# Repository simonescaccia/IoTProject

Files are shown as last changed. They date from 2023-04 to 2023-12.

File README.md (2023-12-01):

# Irrigation Water Leakage System

## Description

Our project is designed to offer some smart functionalities to an irrigation system. Our main goal is to keep track of water usage and leakages, in order to avoid the waste of water. In detail, the system provides measurements about water flow at the source and it detects possible water leakages through irrigation pipes, triggering a proper alarm.

[Concept](https://github.com/simonescaccia/Irrigation-Water-Leakage-System/blob/main/Concept.md) provides details from the user perspective, while [Design](https://github.com/simonescaccia/Irrigation-Water-Leakage-System/blob/main/Design.md) provides technical details about the project. Finally, [Evaluation](https://github.com/simonescaccia/Irrigation-Water-Leakage-System/blob/main/Evaluation.md) focuses on performance issues.

Look at our [Hackaster.io tutorial](https://www.hackster.io/508104/water-leakage-detection-system-fc7f69).

## Video

Video of the Prototype in the environment: [prototype](https://www.youtube.com/watch?v=hoUJ2N8BXHc)

Video of the Simulation on IoT-Lab: [simulation](https://youtu.be/vylREJ1_cT4)

Video of the Presentation of the Project: [presentation](https://www.youtube.com/watch?v=7PrMZpjj8rQ)

## People

| People | Linkedin | Github |
|--- |--- |--- |
| Riccardo Gobbato | [Linkedin](https://www.linkedin.com/in/riccardo-gobbato-380674251/) | [Github](https://github.com/RicGobs) |
| Simone Scaccia | [Linkedin](https://www.linkedin.com/in/simone-scaccia-40b631210/) | [Github](https://github.com/simonescaccia) |
| Pasquale Mocerino | [Linkedin](https://www.linkedin.com/in/pasquale-mocerino-29088b1a2/) | [Github](https://github.com/pasqualemocerino) |

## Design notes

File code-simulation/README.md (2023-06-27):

# Irrigation Water Leakage System RIOT code

## IoT-Lab experiment connection
Create a new IoT-Lab experiment with the needed number of nodes for the simulation. In our case, we defined an infrastructure with 8 nodes, one for each ESP32. Then, after properly setting an SSH key on IoT-Lab, connect through the following command:

    ssh <username>@saclay.iot-lab.info
    
Default 4.9 version of ARM gcc toolchain is not compatible, so run:
    
    source /opt/riot.source 
    
In order to check current gcc version the following command is available:
    
    arm-none-eabi-gcc --version
 
In our case, we refer to 2023.04 RIOT-OS version.

Clone RIOT-OS repository with:

    git clone https://github.com/RIOT-OS/RIOT.git -b 2023.04

Then clone our repository:

    git clone https://github.com/simonescaccia/Irrigation-Water-Leakage-System.git

At this point compile the code with:

    <login>@saclay:~/Irrigation-Water-Leakage-System/code$ make clean all

To flash the firmware:

    <login>@saclay:~/Irrigation-Water-Leakage-System/code$ iotlab-node --flash bin/b-l072z-lrwan1/irrigation-water-leakage-detection.elf -l saclay,st-lrwan1,<node-id> -i <experiment-id>
      
The values node-id and experiment-id can be easily retrieved from IoT-Lab dashboard.
    
Now it is possible to access to the RIOT shell running on the node using netcat:
    
    nc st-lrwan1-<node-id> 20000
    
If the console is empty, using:
    
    setup
    
the output will print out.

## Node configuration

Input: node architecture file, self id

Output: how I am (source_lora_ttn node, source_lora_p2p node, fork node, branch node)

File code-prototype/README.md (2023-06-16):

# Irrigation Water Leakage System RIOT code-prototype

## Introduction
In this folder there are three directories, one per each algorithm implemented. <br/>
We suggest to use the algorithm SyncAck because it is the best one, read the evaluation in the documentation for the motivations. <br/>
There is also the code for the MQTT Bridge, this has to be executed in the device that you want to use as bridge for AWS. <br/>

## How to run the code
Firstly, you have to download mosquitto, go to the site https://github.com/eclipse/mosquitto and follow the instructions. <br/>

Secondly, you have to connect your computer and AWS following this guide https://aws.amazon.com/it/blogs/iot/how-to-bridge-mosquitto-mqtt-broker-to-aws-iot/. <br/>

Then, download RIOT from github:

    git clone https://github.com/RIOT-OS/RIOT.git

Go in RIOT folder and then in the directory /example, download here our code, go in the directory of the SyncAck code (you can do the same for the other algorithms):

    cd RIOT/examples/
    git clone https://github.com/simonescaccia/Irrigation-Water-Leakage-System.git
    cd /Irrigation-Water-Leakage-System/code-prototype/code-ack
    
Now try to do make of the code with command (change type of board and port if needed):

    sudo BOARD=esp32-heltec-lora32-v2 BUILD_IN_DOCKER=1 DOCKER="sudo docker" PORT=/dev/ttyUSB0 make all

If all works, connect your board and do (repeat the same thing for the other board, changing the value of the variable "BOARD" to 0 for Source or 1 for Son):

    sudo BOARD=esp32-heltec-lora32-v2 BUILD_IN_DOCKER=1 DOCKER="sudo docker" PORT=/dev/ttyUSB0 make flash term

Now your ESP32 are working and are sending messages to the MQTT topic selected. Open another terminal, go in the correct directory and launch the command:

    cd /Irrigation-Water-Leakage-System/code-prototype/
    python3 client.py
    
This script take the values sent by the ESP32s and redirect them to AWS.

### Common errors
For this project you need two different boards, one for the Source and one for the Son. <br/>
Before launching the code, change the private values of the code like information of the WI-FI and AWS properties.

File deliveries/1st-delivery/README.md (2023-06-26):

# Smart Irrigation System

## People

| People | Linkedin | Github |
|--- |--- |--- |
| Riccardo Gobbato | [Linkedin](https://www.linkedin.com/in/riccardo-gobbato-380674251/) | [Github](https://github.com/RicGobs) |
| Simone Scaccia | [Linkedin](https://www.linkedin.com/in/simone-scaccia-40b631210/) | [Github](https://github.com/simonescaccia) |
| Pasquale Mocerino | [Linkedin](https://www.linkedin.com/in/pasquale-mocerino-29088b1a2/) | [Github](https://github.com/pasqualemocerino) |

## Description

Our project is designed in order to offer some smart functionalities to an irrigation system to keep track of water usage and leakages, in order to avoid the waste of water. In particular the system measures the humidity of the soil, provides a proper water flow to specific crop through the selective opening of solenoid valves and detects possible water leakages through irrigation pipes.

## Links

[Concept](./Concept.md)\
[Design](./Design.md)\
[Evaluation](./Evaluation.md)

## Video

It will be uploaded soon

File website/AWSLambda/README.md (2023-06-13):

# AWSLambda
This folder contains Python scripts used for AWS Lambda functions. 

In detail, `TakeFunctionLambda.py` processes messages sent from LoRa TTN node of our IoT-Lab simulation to our TTN application, and from this application to AWS. Then it inserts obtained information in two DynamoDB tables. 

The function `WaterMonitorFunction.py`, instead, returns information from the two tables, that are accessed by the web application through a proper AWS API Gateway. 

Finally, the function `WaterSensorLambda.py` is an slightly different Python script used for our prototype in order to retrieve data from tables.

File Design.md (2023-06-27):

# Design

## Components

Our infrastructure is composed of:

* ESP32 MCU
* LoRa support for peer and cloud communication
* Water flow sensor
* Led & Buzzer
* Cloud system (AWS) to collect and store data

### ESP32

The ESP32 manages the different sensors and actuators in the infrastructure and exchanges messages with the other microcontrollers and with the cloud. The main technical issue is that the device will be attached to every object of interest and, apart from the source site, they should be battery powered. MCUs wakes up only when a test is needed, so we modulated a proper duty cicle in order to provide a longer battery lifetime. MCU at the source, instead, is connected to a power cord and does not have energy constraints, but a duty cycle is implemented as well.

### LoRa

LoRa is a physical radio communication protocol, based on spread spectrum modulation techniques derived from chirp spread spectrum (CSS) technology. The protocol is supported by our chosen ESP32 MCUs, allowing a low power and long range communication between microcontrollers in order to accomplish distributed tasks.

### Water flow sensors

Water flow sensors are installed at the water source or pipes to measure the flow rate of water. The chosen metric for flow measurement is liters per minute. The structure of the sensor consists of a valve (from which water can pass) and a water rotor along with a Hall effect sensor (a voltage difference is induced in the conductor due to the rotation of the rotor), measuring the sense and the intensity of the flow. When water flows through the valve, it causes a change of speed of the rotor, calculated as output as a pulse signal. The sensor is powered with a 5 V supply voltage of DC.

Water flow sensors used for our protoype can be found [here](https://www.amazon.it/dp/B079QYRQT5?psc=1&ref=ppx_yo2ov_dt_b_product_details)

### Led & Buzzer

A LED is used to provide a visual alarm indication through blinking.</br>
A buzzer is used to provide an acoustic alarm indication through intermitting activation.

### Cloud system

Data are stored on AWS for long term storage. Then these data can be displayed by farmers in order to gain insights about water usage, in detail the water flow at the source, and pipeline leakages, with the indication of detected location.

## How to detect a leakage

As a first step, we have to reason about our main requirement, leakage detection. In particular, we need to do a feasibility study about how to detect a leakage in a pipeline first, and then how to detect it in a distributed system. The following images show our reasoning process. <br> </br>

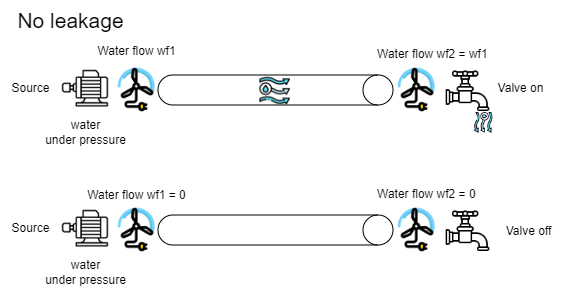
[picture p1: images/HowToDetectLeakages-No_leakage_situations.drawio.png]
no_leakage

<br> </br>
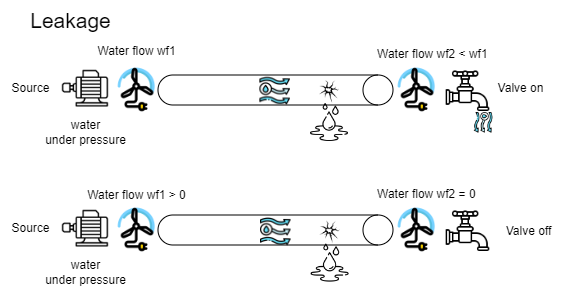
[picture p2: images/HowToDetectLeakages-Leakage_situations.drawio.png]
leakage

<br> </br>
So, by putting the water flow sensors at the extremity of the pipe we can compute the difference of water flow and check if there is a leakage.
If a leakage occur we expect that the water flow at the end of a pipe is different than the water flow at the start.

Our first attempt to detect leakages in distributed infrastructure is the following:
by putting a waterflow sensor befor the fork, we can correctly detect a leakage by computing the difference between the fork water flow and the sum of the branch waterflows. But, it is not enough to satisfy the requirements since we cannot detect which pipe is leaking as in the picture, you can see the same waterflow in both cases but different pipes are leaking.
</br> </br>
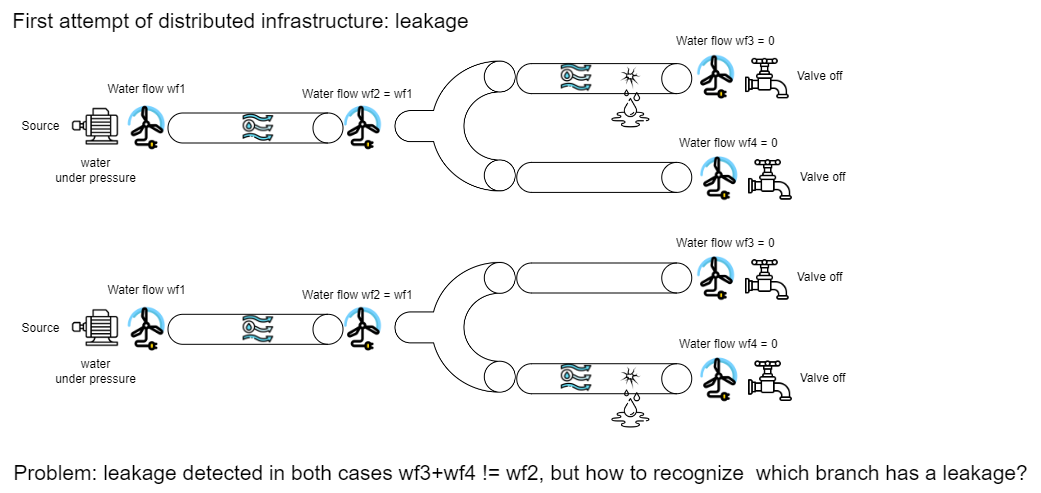
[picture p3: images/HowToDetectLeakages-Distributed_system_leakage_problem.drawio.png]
distributed_problem

<br> <br>
Our proposed solution is to put two water flow sensors insead of one at the fork site. Indeed, in this case, we can detect also the pipe which has a leak.
</br> <br>
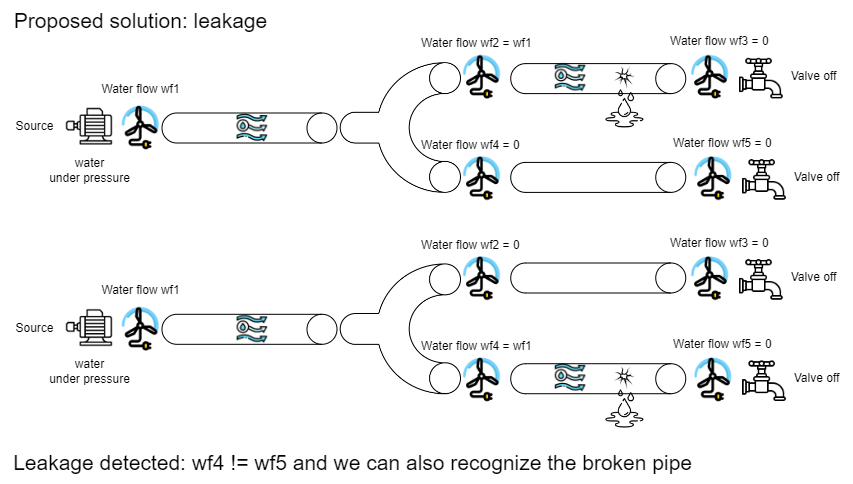
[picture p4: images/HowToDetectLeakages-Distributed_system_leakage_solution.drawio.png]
distributed_solution

<br> </br>
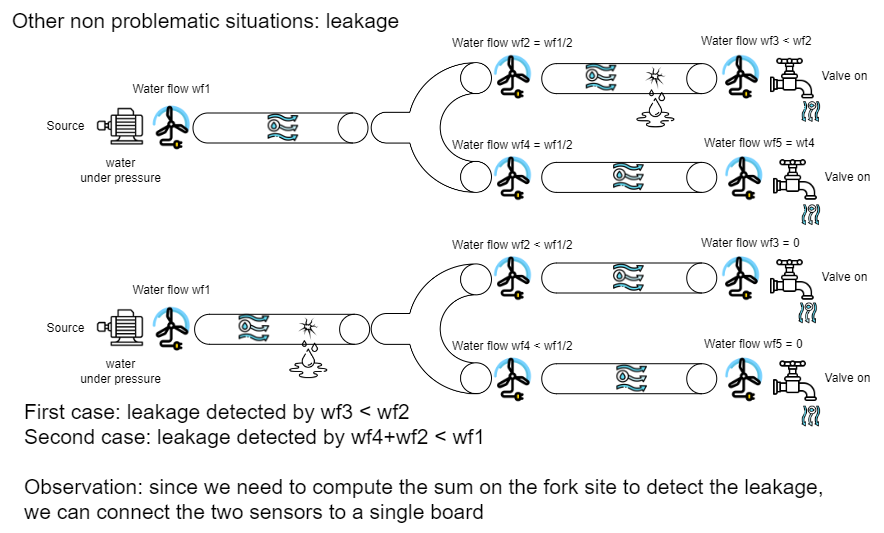
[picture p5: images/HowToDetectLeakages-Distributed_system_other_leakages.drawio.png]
distributed_other


## Architecture

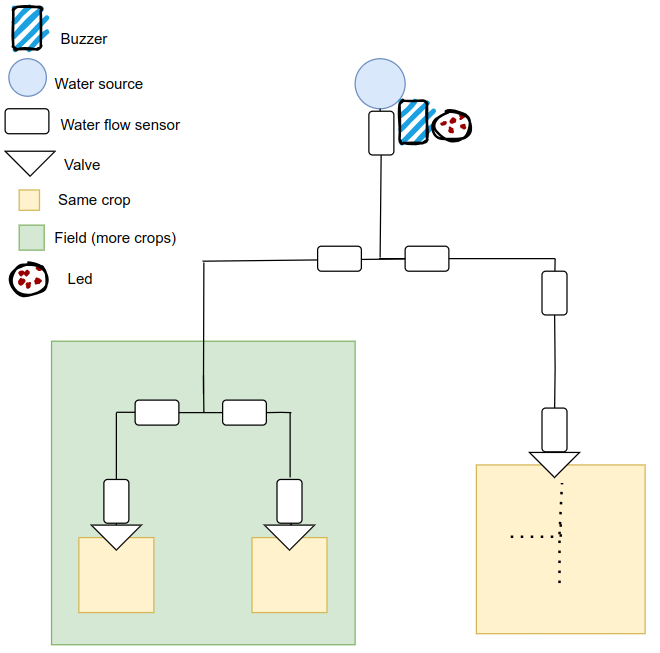
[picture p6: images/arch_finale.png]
field


We propose a tree architecture with a MCU at source site connected to a water flow sensor, a LED and a buzzer. A fork is defined as a site where a single pipe divides itself in two or more output pipes. We place a water flow sensor for each of these diramations, all connected to a single MCU. So. a MCU at each fork site, which can be at different depth levels, is needed. Furthermore, we place a MCU for each pipeline branch, more precisely in correspondence of each irrigation valve, where we place a single water flow sensor connected to the MCU. Our architecture is scalable, so it can be used to control water leakages within a small field with the same crop or to control leakages from pipes irrigating different types of crop in the same field. </br>

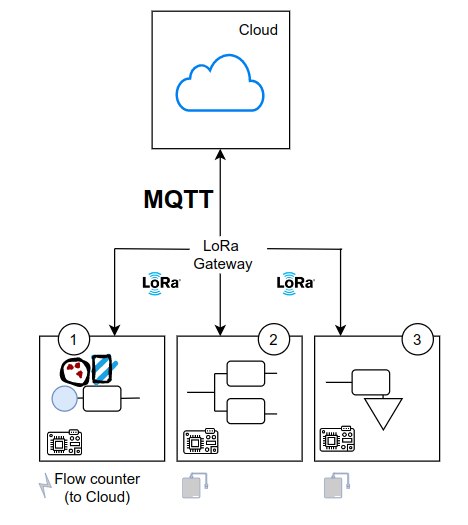
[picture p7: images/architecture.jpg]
architecture


Our system is composed of 3 different pieces:

* MCU near the water source (connected through a power cord) called CHIEF
* MCU near the pipeline fork (using a battery) called FORK
* MCU connected to a water flow sensor at valve site (using a battery) called BRANCH

Every node has an identificative number (in the case of the simulation given by IoT-Lab) and we designed a properly configuration function to extract the information for each node from the topology, given as father-child pairs.
Since in the simulation we used a node for each MCU, our tree architecture can be represented in a more understandable way as follows. </br>

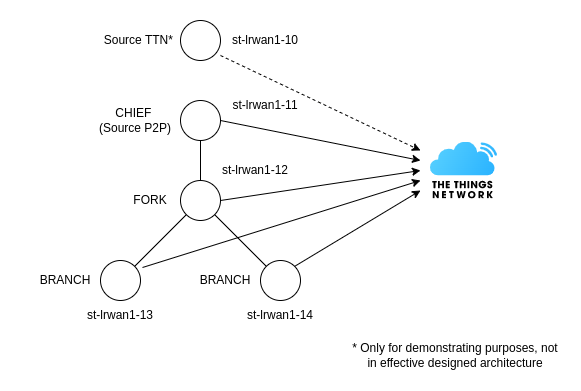
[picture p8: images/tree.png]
tree


In our architecture we preferred to focus our attention on things, with computation performed at nodes rather than in the cloud. So, the cloud only receives (from TTN) data about water flow and leakages that are simply displayed in the GUI. For some techical reasons explained in detail in the description of our simulation, we used a simple node communicating with TTN for demonstrating purposes. However, in the designed architecture each node receiving a flow from the father computes the difference between this flow and its own one and sends data to TTN only in case of leakage.

## Network architecture

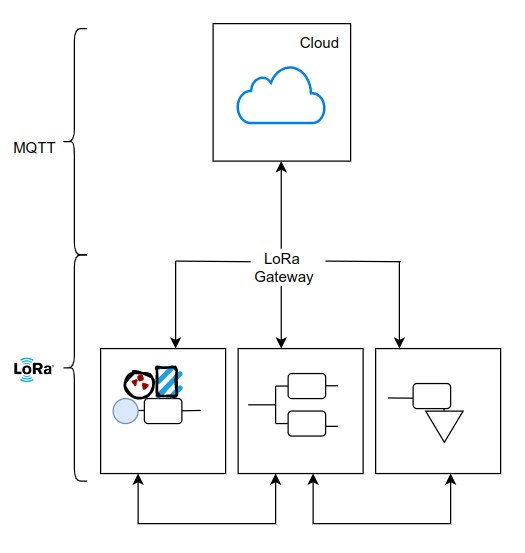
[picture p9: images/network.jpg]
network


The network architecture is focused on checking the actual state of the irrigation system, with a communication between devices based on LoRaWAN and MQTT.

## Prototype

We constructed a real prototype to demonstrate the working principle of the system. It is made up of a linear pipe and two MCUs located at its endopoints, with a water flow sensor for each one, together with a water source and an intermediate valve used to simulate a leakage.

Unfortunately, we found some problems working with LoRa with our chosen ESP32, even if it should be officially supported by RIOT. So, in order to overcome this issue, we decided to switch to WiFi technology only for demonstating purposes. The idea is that when LoRa issue will be hopefully solved soon our project can be adapted with minor changes.
For our prototype, we used the fllowing objects:

* A 1,5 meters long garden hose (20-25 mm ⌀)
* A 1/2 inch garden tap
* A 1/2 inch T-adapter
* 6 metal adjustable hose clamps
* 2 water flow sensors (15-20 mm)
* 2 ESP32 LoRa MCUs  

We started from a 1,5 meters long garden hose with an inner diameter of 20 mm and an outer one of 25 mm. We cut the garden hose into 4 main segments approximately 35 cm long. We placed two segments at the inner endpoints of each water flow sensor and we joined them using the T-adapter. So we connected the tap to the last free endpoint of the T-adapter and the last two segments to the outer endpoints of water flow sensor. We defined a direction for the flow placing the water flow sensors in the correct flow measurement direction. Finally, we connected the water flow sensors to the MCUs and the MCUs to a battery.

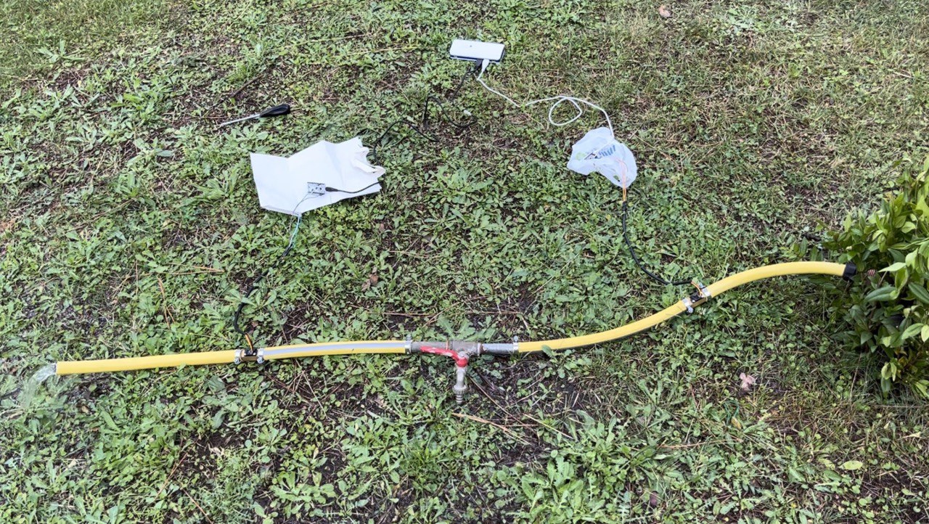
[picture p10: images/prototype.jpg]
prototype


The tap is used to simulate a leakage and it is initially closed. We did not use clamps at first, but we experienced water leaks in correspondence of joints. Therefore we placed 2 clamps at the outer endpoints of each water flow sensor and other 2 for the endpoints of the T-adapter not connected to the tap. In this way we solved the problem of leakages at joints. The water flow sensor of father MCU and the water flow sensor of child MCU are 90cm apart.

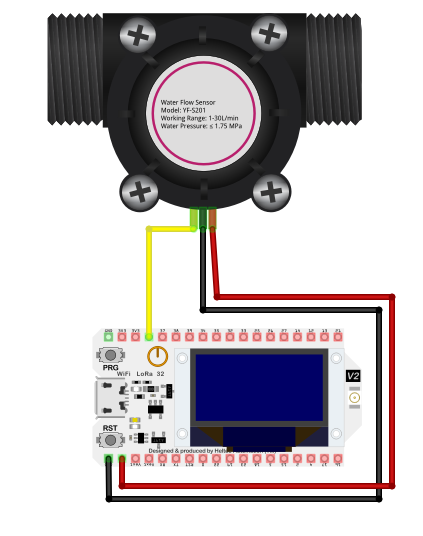
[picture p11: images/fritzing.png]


## Algorithms

### Water leakage detection algorithm

In the following we describe the communication scheme between IoT elements, Edge components, and Cloud components, related to the algorithm for the leakage detection.

We analyse the water flow independently for each segment, intended as the pipe between two adjacent water flow sensors. Given a segment, we will call the node near the water source as 'parent' and the other one as 'child'.
Output water flows at fork site will be evaluated according to given paramters as pipe length or slope.

Test algorithm:

1. Node MCU sends water flow value to its children, if any.
2. If it is a FORK, child MCU computes expected values of water flow, by summing the values of its sensors.
3. Child MCU compares received value with its own value.
4. In case of leakage, child sends an alert to the cloud.

We have tried 3 different algorithms for allow a correct and synchronized test between two diffent nodes. The three algorthms are:

* Ack
* Handdshake
* SyncAck
All the algorithms are available in the directory "code-prototype"

#### Ack

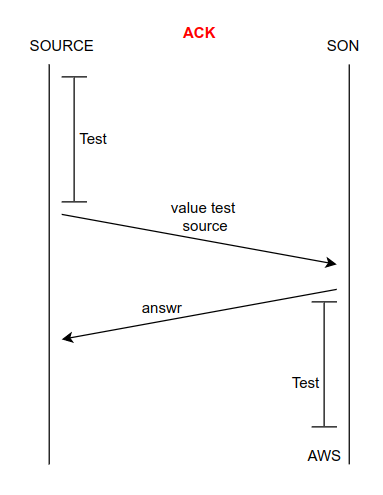
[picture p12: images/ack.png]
ack


This is the first algorithm that we have implemented and it does not work well. Firstly there is a bug in the code, in fact with this code the Son has an higher flow that the Source, and this is not physically possible (if you find the problem, please tell us where is it), Secondly with the data obtained, we have seen that the water flow arriving to the Source (before our architecture) is not stable and the code was not robust against this problem.

In particular the Source controls if there is a water flow, if yes it does the test and sends the value to the Son; the Son obtains the value, sends an "answr" to the Source (used to control the Son is not broken) and starts the test; after that it does the difference between the two values and see if there is a leakage or not, if yes it sends the value of the leakage in L/min to AWS.

For the motivation written before, this system is proned to the false positive and we have stopped the analysis on it.

#### Handshake

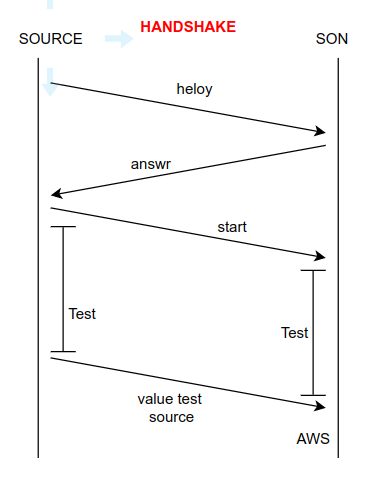
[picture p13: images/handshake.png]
handshake


This is the second algorithm that we have implemented and it works well.

In particular the Source controls if there is a water flow, if yes it sends an "heloy" to the Son, the Son sends an "answr" to the Source, Source sends the message "start" and starts the test; when the Son obtains the "start" it also starts the test; the Source sends to the Son the result of the test and, when the Son has both the values, sees if there is a leakage, if yes it sends the value of the leakage in L/min to AWS.

This system works well but it is uselessly complex and it is less efficient than the next one.

#### SyncAck

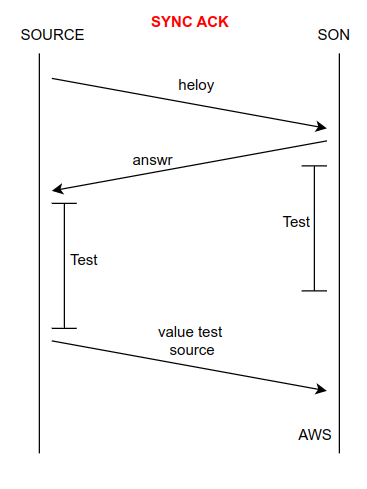
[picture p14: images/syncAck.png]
syncAck


This is the third algorithm that we have implemented and it is the one that will be used in the real scenario.

In particular the Source controls if there is a water flow, if yes it sends an "heloy" to the Son, the Son sends an "answr" to the Source and it also starts the test, Source receives the message "answr" and starts the test; Source sends to the Son the result of the test; when the Son has both the values, sees if there is a leakage, if yes it sends the value of the leakage in L/min to AWS.

This system works well and uses one less message.

In the evaluetion part, it is available the different analysis on the data.

## Simulation

We built a simulation infrastructure on IoT-LAB, to provide a large-scale irrigation water leakage system and to test distributed interaction between MCUs. The communication between nodes is implemented using LoRaMAC, while LoRaWAN and TheThingsNetwork are used to send data to the cloud. Also, we will use this simulation to makes some experiments on energy consumpion using the IoT-LAB monitoring tool.

### Assumptions

The simulation aims to detect leakages in a scalable distributed infrastructure, while the prototype focus on detecting leakages for a single pipe. For this reason, in the simulation we have made some assumptions:

* A code function simulates samples to avoid delays in message propagation, false positives, and all the problems discussed in the prototype. Instead, we will use a logic time to simulate the sampling at the same time.
* Forks on a pipe will divide the water flow into equal parts.
* Since we are simulating samples, we can set the threshold for leakages to 0.

### Iot-Lab Architecture

As mentioned before, to build a scalable infrastucture we need to use three different types of nodes: CHIEF, FORK, and BRANCH. They can cover all the possible cases of a distributed infrastructure.
The minimal architecture of the system should be the following:

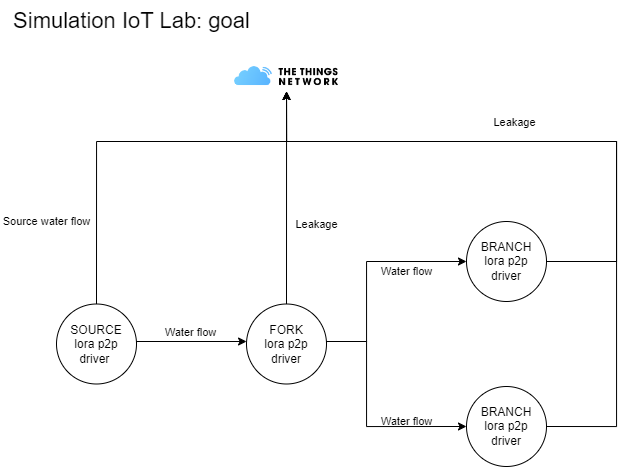
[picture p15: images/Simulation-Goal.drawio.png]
simulation_goal


Node configuration

* Due to the fact that the firmware is distributed, we need to use the same firmware for all the nodes. For this reason, we need to build a configuration file named config.c that can be used for all the nodes, to understand which type of node is and who are its children.
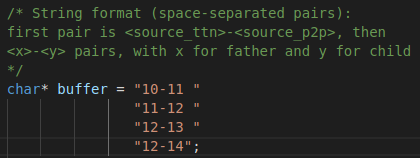
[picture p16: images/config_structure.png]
config_structure

* After flashing the firmware we need to assign an ID to each node compliant with the configuration file.
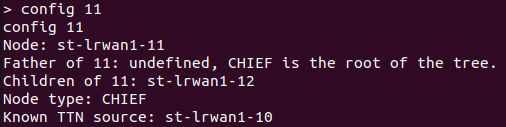
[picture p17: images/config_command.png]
config_command


Parameters

* Since requirements want to detect leakages in a day, we have decided to simulate a day in 60 seconds. Also, we have introduced a parameter called NUMBER_OF_SENDING_PER_DAY that represents the number of samples sent by the node in a day, in order to implement the duty cycle. For the simplicity of the demo, we have set this parameter to 3 but the value for the real application it is discussed in the Evaluation page.

Sample generator

* The sample generator is a function that simulates the sampling of the water flow. Its aim is also to test the various leakage scenario discussed in the 'How to detect a leakge' paragraph.

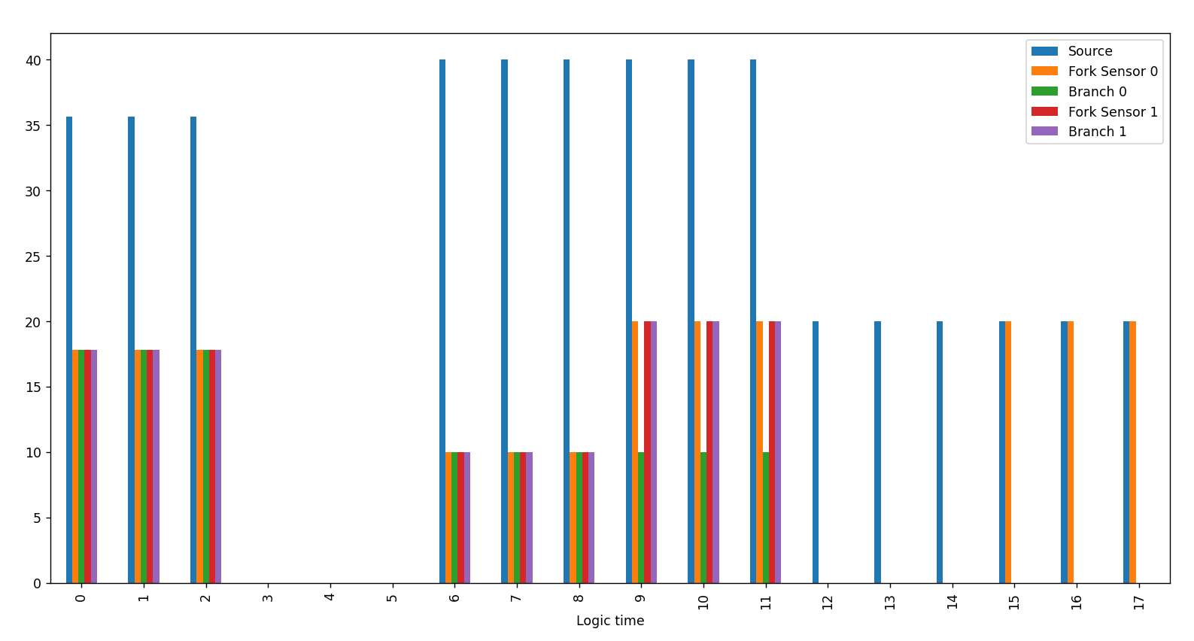
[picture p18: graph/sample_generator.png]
sample_generator


* logic_time in [0, 2]: Simulate no LEAKAGE with water usage - Test also float water flow mesurements
* logic_time in [3, 5]: Simulate no LEAKAGE without water usage
* logic_time in [6, 8]: Simulate a LEAKAGE between the CHIEF and the FORK with water usage
* logic_time in [9, 11]: Simulate a LEAKAGE between the FORK and a BRANCH with water usage
* logic_time in [12, 14]: Simulate a LEAKAGE between the CHIEF and the FORK without water usage
* logic_time in [15, 17]: Simulate a LEAKAGE between the FORK and a BRANCH without water usage

Comunication protocols

* The nodes communicate with each other using RIOT-OS Semtech SX127x radios drivers implementation, sending asynchronous messages containing the water flow value.
* Each node sends leakage messages to The Things Network (TTN) using a RIOT adaption of Semtech LoRaMAC implementation.

But, during the implementation we have found some difficulties on integrating the Semtech LoRaMAC implementation with the RIOT-OS Semtech SX127x radios drivers implementation. In particular, initialising both the drivers on the same node, causes some conflicts that invalidate the communication of both node-TTN ans node-to-node.
For this reason we have decided to use another node to connect our infrastructure to TTN, and in order to be able to send leakage messages generated by the nodes using LoRaMAC, we have decided to pick these leakage information directly from the sample generator since building a UART communication between the nodes requires time that can be used to solve our initial problem i.e. the conflicts between the LoRa drivers.

So, our implementation is the following:

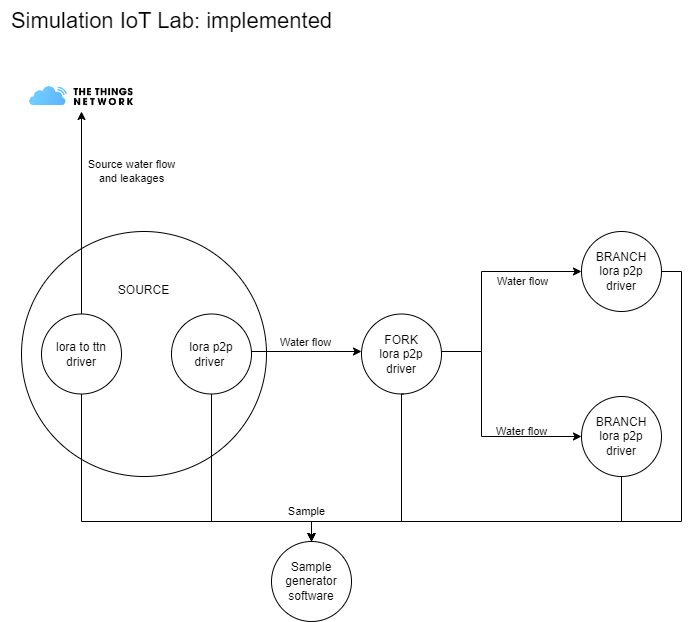
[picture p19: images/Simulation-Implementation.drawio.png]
simulation_implementation


Messages

* Semtech SX127x radios drivers implementation allows to send messages of at most 32 bytes in broadcast mode. This implies that a node in the listen mode can receive messages from all the nodes in the range. For this reason, we have decided to use a message structure that contains the following information:

  * The app id: 0000
  * The id of sender node
  * The id of receiver node
  * A flag that indicates if the message is a value
  * The value of the water flow
  * The logic time

* When a node receives a message, it checks if the message is sent by our infrustructure and if the message is directed to it.
* We have observed that RIOT SX127x drivers fails to handle messages with a payload higher than 32 bytes which causes a stack overflow and the crash of the node. That's a critical problem because messages sent by external nodes can cause the crash of our infrastructure.

Radio

* The radio can't be used to send a message and listen at the same time. Then, with a certain probability that increases with the number of sending messages per day, during the message transmission, incoming messages can be lost.

### Open Issues

* Integration of lora sx127x drivers for p2p communication and loramac for ttn communication.
* Using real samples instead of simulated ones.
* Crash of the node when receiving messages with a payload higher than 32 bytes.

## Dashboard

### AWS Architecture

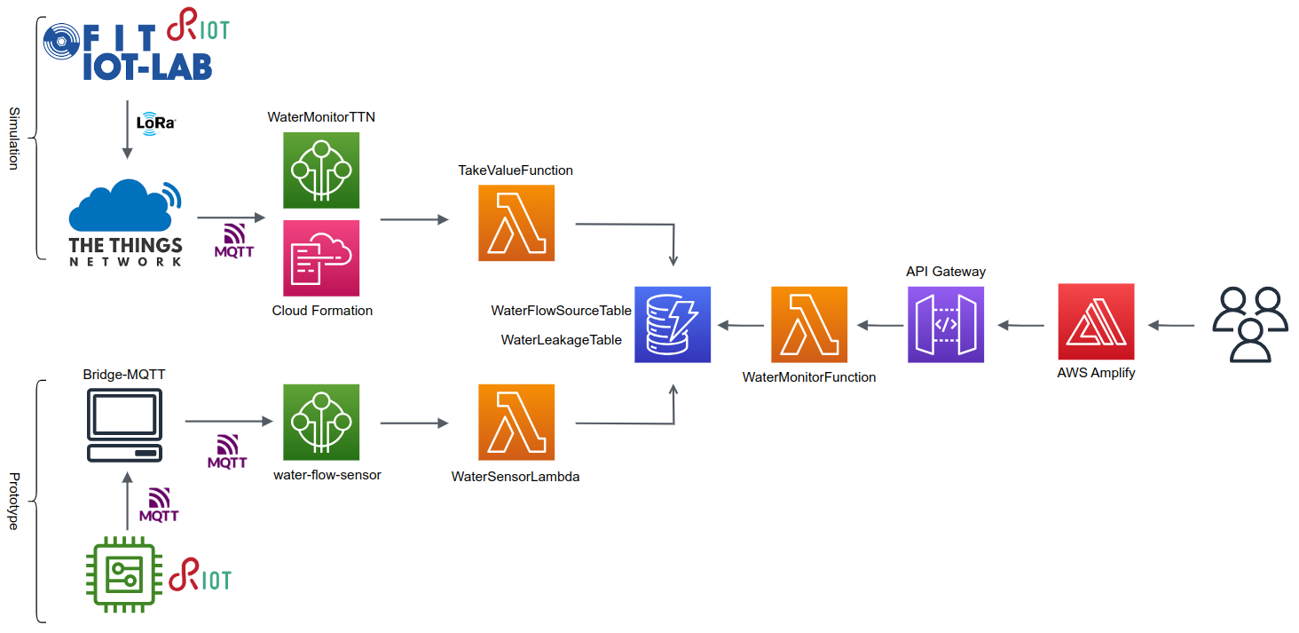
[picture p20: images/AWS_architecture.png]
AWS

The AWS architecture above shows our cloud design. In detail, data are generated both from the prototype and the simulation, but sent to AWS through a MQTT-Bridge for the prototype and TTN for the simulation. Data are sent to AWS IoT Core, using also AWS CloudFormation in the case of TTN. With two proper AWS Lambda functions data are stored in two NoSQL DBs, one for the water flow at the source and one for water leakages. With a separate unique Lambda function, data are retrieved form DBs and associated to an API deployed with AWS API Gateway. The website frontend, taken data dynamically from API endpoint, has been deployed with AWS Amplify.

### Website

Here it is a demonstration of website content:

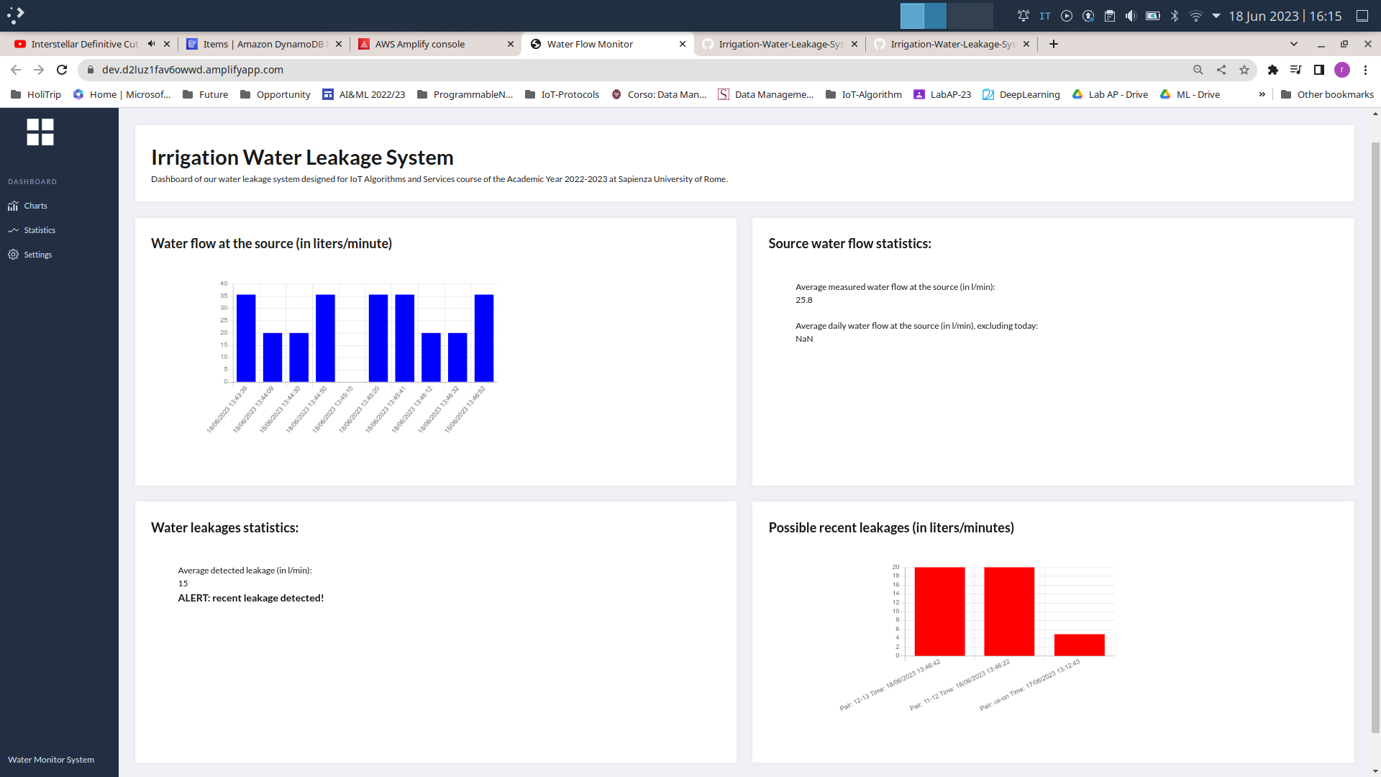
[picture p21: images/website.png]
website


From the website user can monitor water flow at the source looking at last 10 measurements displayed in the upper graph and checking some statistics about average water flow. A proper alert is shown in case of leakage, with leakages displayed in the lower graph with correct location and quantity. Also here, some statistics can be retrieved.

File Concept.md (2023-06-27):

# Concept

## Problem

Today irrigation does often not keep into account possible water leaks from watering pipes. This superficial management is leading to a huge waste of water, which is one of main causes of drought. Agriculture is the most water demanding sector, with the 40% of total water usage per year in Europe.
In Italy over 26 billion of cube meters of water per year are consumed: around 55% is reserved for agriculture, 27% for the industry and 18% for the city. However, withdrawal of water effectively exceeds 33 billion of cube meters per year: this difference is motivated by the waste of around 22% of total water and 17% of these leakages are related to the agricultural sector. However, our project can also be used to monitor the state of regular water distribution system, if a proper adaptation is given.

## Proposed solution

Our proposed solution consists of an interface through which it is possible to monitor the irrigation system. The user can know if a leakage is detected and where it is located, as well as the flow of water at the source site. Another available information is the past water usage schedule, with the relative periodical measurements of water flows.

## Use cases

Our system allows to do the following tasks:

* Leakages detection, quantification and localization
* Water usage monitoring

## User requirements

The starting point of our analysis is the collection of user requirements. In our context, there are some fixed parameters, mainly related to the chosen infrastructure, while other parameters should be finetuned according to the specific final user of the application, ideally a farmer owning a variable field. To cope with this issue, we made reasonable assumptions about these parameters, and we also guaranteed the scalability of the system according to user needs.

### Alarm system

We thought about suitable actuators to use in order to indicate an alarm condition. A simple LED with a buzzer are certainly a good option.
Obiouvsly, it makes no sense to place these actuators in the middle of a field, because it is unlikely that someone will see or hear something. Instead, they can be placed near water source, so they can be easily noticed and constantly connected to electric power.

### Events

The main events we are interested in are certainly water flow changes. We wish to monitor the water flow at the source and also to know about current possible leakages as the results of a proper water leakage detection algorithm comparing flow changes at different nodes of the irrigation system.

### Communication protocol

LoRa is a suitable technology for different reasons:

* It uses low bandwidth, and this is a great advantage in our context. In fact, we need to exchange simple data, namely water flow measurements, so LoRa is certainly a good option.
* It can send data on long ranges. It is not an immediate advantage in our architecture, because we implemented a peer-to-peer communication with adjacent nodes. However, it can be very useful firstly to reach also far LoRa gateways and on large scale systems to exchange data between distant nodes, if needed.
* It works with low power consumption, and this is a crucial added value to the protocol since we use battery-powered MCUs.

### Energy consumption

* We thought about the best battery lifetime for our MCUs and our conclusion was to reason over the needed sampling cycles and the utilization period of the system. So, 1 year of battery life was considered as a good option.
* We also thought about the possibility to recover energy from water flow sensor dynamics, for example with a dynamo. However, this solution was not feasible for our hardware because of the impossibility to access to the enclosed rotor in a proper way.

## HOW WE HAVE WORKED
We have created three subtopic, you can see all this work in [Design](https://github.com/simonescaccia/Irrigation-Water-Leakage-System/blob/main/Design.md) and [Evaluation](https://github.com/simonescaccia/Irrigation-Water-Leakage-System/blob/main/Evaluation.md):
1. Prototype:
* build the physical prototype, solving the technical problems
* create different algorithms to synchronize the nodes
* connect prototype and AWS with MQTT
* take data to choose the best algorithm
* take data to set a correct threshold
2. Simulation in IoT-Lab:
* build the infrastructure of the simulation, solving the technical problems
* send data between nodes with lora-semtech
* create a sample generator function to simulate water flow rates and leakages
* take data of the energy consumption
3. Connection of IoT-Lab and AWS:
* create a node that send data to TTN using the sample generator function
* integrate TTN and AWS
* create the rules, the dynamoDB and the lambda functions to work with the data
* create the website page with Amplify

## Possible improvements
There are some possible improvements for the future of this project:
* Fixing the problem of the libraries lora-semtech and lora-wan to remove the redundant Source TTN
* Transpose the code of the simulation in a real environment using some boards with a working lora-wan library
* Adding the buzzer and the led
* Using real samples instead of simulated ones, in IoT-Lab
* Crash of the node when receiving messages with a payload higher than 32 bytes, in IoT-Lab

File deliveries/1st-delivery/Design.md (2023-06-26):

# Design

## Architecture 
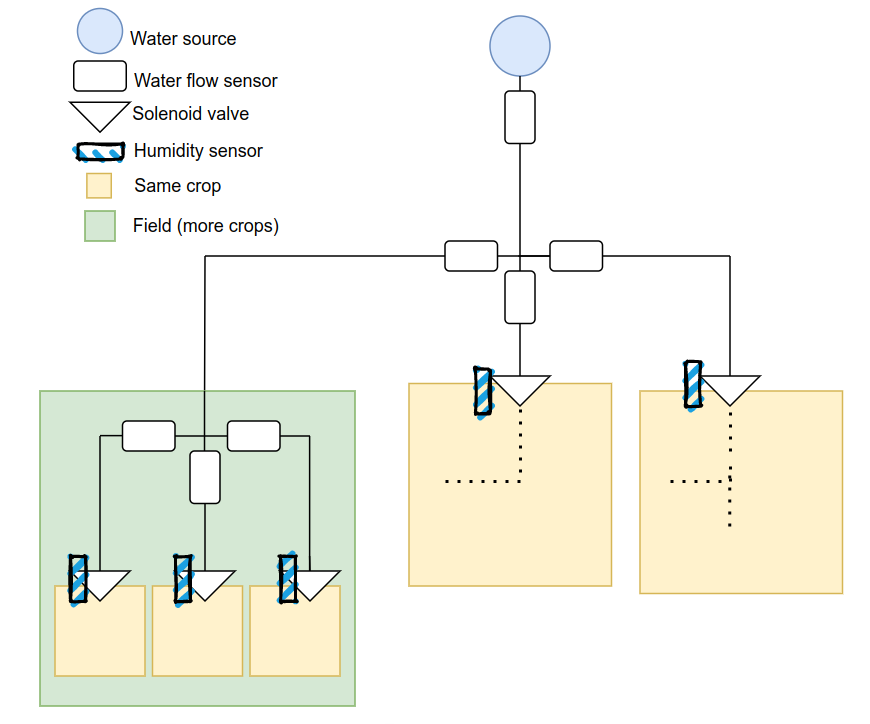
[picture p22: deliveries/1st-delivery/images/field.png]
Field1
 <br/>
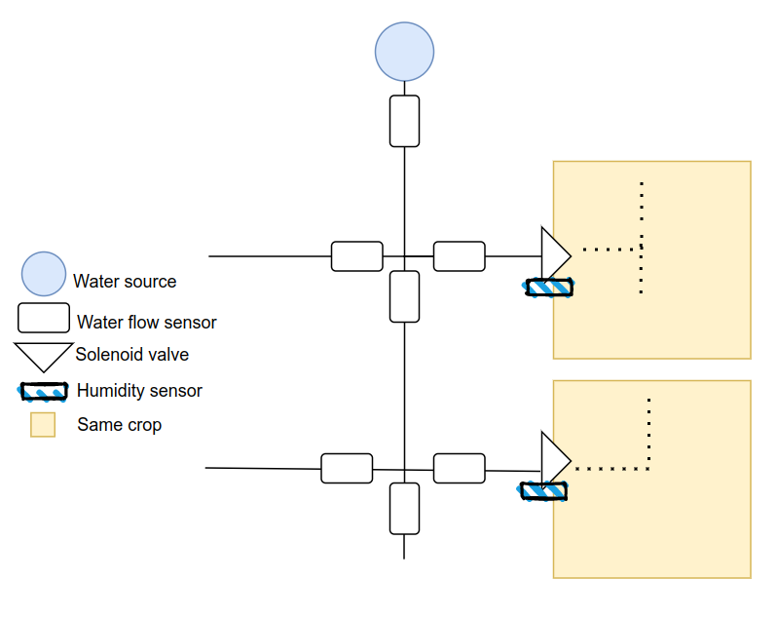
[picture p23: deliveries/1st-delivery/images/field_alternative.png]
Field2
 <br/>
Our architecture is scalable and can be used to control the water within a small field, if there is the same crop, or can be used to control different types of crop in the same field. For every field a MCU at the fork site (that can be at different depth levels) is needed, plus a MCU for each pipeline branch.</br>
We have proposed two different possibilities of set of fields (we will analyse which one is the better or if there are other possible architecture).

## High level diagram
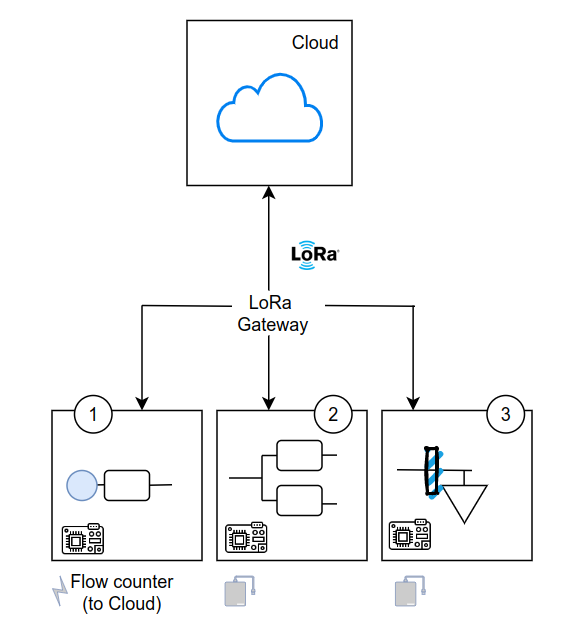
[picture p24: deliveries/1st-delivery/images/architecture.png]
architecture
 <br/>
Our system is composed of 3 different pieces:
* MCU near the water source (connected through a power cord) called CHIEF
* MCU near the pipeline fork (using a battery) called FORK, with an ID for the fork and a NUMBER for each branch water flow sensor
* MCU connected to a soil humidity sensor and a solenoid valve (using a battery) called BRANCH and with a NUMBER (consistent with the NUMBER value in the relative FORK)

## Components
Our infrastructure is composed of:
* ESP32 MCU with LoRa support for peer and cloud communication 
* Water flow sensor
* Soil humidity sensor 
* Solenoid valve
* Cloud system (AWS) to collect and store data

### ESP32
The ESP32 manages the different sensors and actuators in the infrastructure and exchanges messages with the other microcontrollers and with the cloud. The main technical issue is that the device will be attached to every object of interest and thus should be battery powered:
* CHIEF is connected to a power cord and does not have energy problems
* FORK wakes up rarely and only when a test is needed, so it has a small duty cicle
* BRANCH wakes up periodically in order to check the humidity of the soil and possibly irrigate crop

### LoRa
LoRa is a physical radio communication protocol, based on spread spectrum modulation techniques derived from chirp spread spectrum (CSS) technology. The protocol is supported by our chosen ESP32 MCUs, allowing a low power and long range communication between microcontrollers in order to accomplish distributed tasks.

### Sensors
#### Water flow sensors
Water flow sensors are installed at the water source or pipes to measure the flow rate of water. The relative metric is as liters per hour or cubic meters, to be scaled in our context. The structure of the sensor consists of a plastic valve (from which water can pass) and a water rotor along with a Hall effect (a voltage difference is induced in the conductor due to the rotation of the rotor) sensor, measuring the sense and the intensity of the flow. When water flows through the valve, it causes a change of speed of the rotor, calculated as output as a pulse signal. The sensor contains three wires, one for supply voltage (5 V of DC), one for the ground and one to collect output from Hall effect sensor. 

#### Soil humidity sensors
Soil humidity sensors are fork-shaped probes inserted into the soil, with two exposed conductors, hence acting as a variable resistor. The resistance varies inversely with soil humidity. In fact capacitance is used in order to measure dielectric permittivity of the soil, which is a function of the water content. The sensor produces an output voltage proportional to the dielectric permittivity (so inversely proportional to resistance), and therefore the water content of the soil (soil moisture level). Only four pins are required to connect: AO (Analog Output), generating analog output voltage, DO (Digital Output) indicating whether the soil moisture level is within the limit, VCC for power supply (from 3.3 V to 5 V) and GND for the ground.

### Actuators
#### Solenoid valves
Solenoid valves are electromechanically operated valves converting electric energy into mechanical energy. The main purpose is to automatically regulate the movement of water, removing the need of manual control. The actuator consists of a solenoid (or electromagnet) and a valve. The electromagnetic coil within the solenoid (activated with energy supply) is employed to either open or close the valve orifice through a plunger.

### Cloud system
Data are stored on AWS for long term storage. These data can then be queried by farmers in order to gain insights about water usage and pipeline leakages. The farmer can also select a particular crop for a field.

## Network architecture 
network <br/>
The network architecture is focused on checking the actual state of the irrigation system, with a communication between devices based on LoRaWAN and MQTT. We will also make some considerations about the scalability of different possible network schemes.

## Algorithms 
### Water leakage detection algorithm
messages <br/>
This is the communication scheme between IoT elements, Edge components, and Cloud components, related to the algorithm for the leakage detection.

### Automated irrigation algorithm
We provide a pseudocode sketch of the automated mechanism of irrigation:

    def automated_irrigation(humidity_threshold):

        humidity_level = get_humidity() // From soil humidity sensor
    
        if (humidity_level < humidity_threshold):
            open()  // Open signal to solenoid valve
        
            while (humidity_level < humidity_threshold):
                wait(time_interval) // Wait some time to make humidity change
                humidity_level = get_humidity()
            
            close()  // Close signal to solenoid valve

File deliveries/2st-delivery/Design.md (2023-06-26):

# Design

## Architecture

field <br/>

We propose a tree architecture with a MCU at source site connected to a water flow sensor, a LED and a buzzer. A fork is defined as a site where a single pipe divides itself in two or more output pipes. We place a water flow sensor for each of these diramations, all connected to a single MCU. So. a MCU at each fork site, which can be at different depth levels, is needed. Furthermore, we place a MCU for each pipeline branch, more precisely in correspondence of each irrigation valve, where we place a single water flow sensor connected to the MCU. Our architecture is scalable, so it can be used to control water leakages within a small field with the same crop or to control leakages from pipes irrigating different types of crop in the same field. </br>

Since in the simulation we used a node for each MCU, our tree architecture can be represented in a more understandable way as follows.

tree <br/>

## High level diagram

architecture <br/>
Our system is composed of 3 different pieces:

* MCU near the water source (connected through a power cord) called CHIEF
* MCU near the pipeline fork (using a battery) called FORK, with an ID for the fork and a NUMBER for each branch water flow sensor
* MCU connected to a water flow sensor at valve site (using a battery) called BRANCH and with a NUMBER (consistent with the NUMBER value in the relative FORK)

## Components

Our infrastructure is composed of:

* ESP32 MCU with LoRa support for peer and cloud communication 
* Water flow sensor
* LED
* Buzzer
* Cloud system (AWS) to collect and store data

### ESP32

The ESP32 manages the different sensors and actuators in the infrastructure and exchanges messages with the other microcontrollers and with the cloud. The main technical issue is that the device will be attached to every object of interest and thus should be battery powered:

* CHIEF is connected to a power cord and does not have energy problems
* FORK and BRANCH wakes up only when a test is needed, so we modulated a proper duty cicle in order to provide a longer battery lifetime

### LoRa

LoRa is a physical radio communication protocol, based on spread spectrum modulation techniques derived from chirp spread spectrum (CSS) technology. The protocol is supported by our chosen ESP32 MCUs, allowing a low power and long range communication between microcontrollers in order to accomplish distributed tasks.

### Sensors

#### Water flow sensors

Water flow sensors are installed at the water source or pipes to measure the flow rate of water. The relative metric is as liters per hour or cubic meters, to be scaled in our context. The structure of the sensor consists of a plastic valve (from which water can pass) and a water rotor along with a Hall effect sensor (a voltage difference is induced in the conductor due to the rotation of the rotor), measuring the sense and the intensity of the flow. When water flows through the valve, it causes a change of speed of the rotor, calculated as output as a pulse signal. The sensor is powered with a 5 V supply voltage of DC.

You can find our water flow sensor here: https://www.amazon.it/dp/B079QYRQT5?psc=1&ref=ppx_yo2ov_dt_b_product_details

### Actuators

#### LED
A LED is used to provide a visual alarm indication through blinking. 

#### Buzzer
A buzzer is used to provide an acoustic alarm indication through intermitting activation.

### Cloud system

Data are stored on AWS for long term storage. These data can then be queried by farmers in order to gain insights about water usage and pipeline leakages.

## Prototype architecture
For our prototype, we used the fllowing objects:
* A 1,5 meters long garden hose (20-25 mm ⌀)
* A 1/2 inch garden tap
* A 1/2 inch T-adapter
* 6 metal adjustable hose clamps (16-25 mm)
* 2 water flow sensors 
* 2 ESP32 LoRa MCUs  

We started from a 1,5 meters long garden hose with an inner diameter of 20 mm and an outer one of 25 mm. We cut the garden hose into 4 main segments approximately 35 cm long and a smaller one around 10 cm long. We placed two segments at the endpoints of each water flow sensor and we joined them using the T-adapter. We connected the tap to the last free endpoint of the T-adapter and the smallest pipe segment to the tap dispenser. So we connected the water flow sensors to the MCUs. 
The tap is used to simulate a leakage and it is initially closed. We did not use clamps at first, but we experienced water leaks in correspondence of joints. Therefore we placed 2 clamps at the endpoints of each water flow sensor and other 2 for the endpoints of the T-adapter not connected to the tap. 

The final protoype architecture is the following.

## Network architecture 

network <br/>
The network architecture is focused on checking the actual state of the irrigation system, with a communication between devices based on LoRaWAN and MQTT. We will also make some considerations about the scalability of different possible network schemes.

## Algorithms

### Water leakage detection algorithm

This is the communication scheme between IoT elements, Edge components, and Cloud components, related to the algorithm for the leakage detection.

We analyse the water flow for each segment, intended as the pipe between two adjacent water flow sensors. Output water flows at fork site will be evaluated according to given paramters as pipe length or slope.

Algorithm idea (CHIEF duty cycle):

(DUE_TEST is set to true every 24 hours, NO_TEST is initialized to 0)

1. If flag DUE_TEST is set or NO_TEST is set, CHIEF checks if there is water flow (regular water usage monitoring).
2. If there is a water flow, it starts the test and sets the flags to 0.
3. If there is not a water flow, it sets NO_TEST.

Test algorithm:

1. Node MCU sends water flow value to its children.
2. If it is a FORK, child MCU computes expected values of water flow
3. Child MCU compares received value with its own value.
4. In case of error, child sends an alert to the cloud.

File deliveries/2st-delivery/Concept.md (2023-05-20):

# Concept

## Problem

Today irrigation does often not keep into account possible water leaks from watering pipes. This superficial management is leading to a huge waste of water, which is one of main causes of drought. Agriculture is the most water demanding sector, with the 40% of total water usage per year in Europe.
In Italy over 26 billion of cube meters of water per year are consumed: around 55% is reserved for agriculture, 27% for the industry and 18% for the city. However, withdrawal of water effectively exceeds 33 billion of cube meters per year: this difference is motivated by the waste of around 22% of total water and 17% of these leakages are related to the agricultural sector. However, our project can also be used to monitor the state of regular water distribution system, if a proper adaptation is given. 

## Proposed solution

Our proposed solution consists of an interface through which it is possible to monitor the irrigation system. The user can know if a leakage is detected and where it is located, as well as the flow of water at the source site. Another available information is the past water usage schedule, with the relative periodical measurements of water flows.

## Use cases

Our system allows to do the following tasks:

* Leakages detection, quantification and localization
* Water usage monitoring

## User requirements
The starting point of our analysis is the collection of user requirements. In our context, there are some fixed parameters, mainly related to the chosen infrastructure, while other parameters should be finetuned according to the specific final user of the application, ideally a farmer owning a variable field. To cope with this issue, we made reasonable assumptions about these parameters, and we also guaranteed the scalability of the system according to user needs.

### Detect water leakages
* How can we detect leakages? Conceptually, we measure the water flow at different adjacent sites of the irrigation system and we compare these measurements in order to detect anomalies, according to a specific detection algorithm.
* The accuracy is computed considering the percentage of correct leakage identification on the total number of experiments.
* We also thought about the possibility to binary classify every state as faulty or as correct, focusing on the analysis of False Positive and False Negative events.

### Reaction time
We thougt about a proper time bound on the interval from leakage manifestation until detection. Some common values for water flow rate given by irrigation pumps are from 20 to 80 liters of water per minute. Now, there is much variability as concerns the irrigation procedure, depending on the type of crop. However, in most cases, the irrigation procedure should last only few minutes per day. Assuming also a severe leakage, it is difficult that more than 30% of water will be lost. So, in the worst case, from 6 to 24 liters of water per minute will be lost. A reasonable assumption is to tolerate at most 24 hours of no detection. These considerations are at the basis of our concept of duty cycle.

### Alarm system
We thought about suitable actuators to use in order to indicate an alarm condition. A simple LED with a buzzer are certainly a good option.
Obiouvsly, it makes no sense to place these actuators in the middle of a field, because it is unlikely that someone will see or hear something. Instead, they can be placed near water source, so they can be easily noticed and constantly connected to electric power.

### Events 
The main events that we are interested in are certainly water flow changes. We wish to monitor the water flow at the source and also the one at different sites of the system, in order to compare measurements and detect possible changes of flow.

### Communication protocol
LoRa is a suitable technology for different reasons:
* It uses low bandwidth, and this is a great advantage in our context. In fact, we need to exhange simple data, namely water flow measurements, so LoRa is certainly a good option.
* It can send data on long ranges. It is not an immediate advantage in our architecture, because we implemented a peer-to-peer communication with adjacent nodes. However, it can be very useful firstly to reach also far LoRa gateways and on large scale systems to exchange data between distant nodes, if needed.
* It works with low power consumption, and this is a crucial added value to the protocol since we use battery-powered MCUs.

### Energy consumption
* We thought about the best battery lifetime for our MCUs and our conclusion was to reason over the needed sampling cycles and the utilization period of the system. So, 1 year of battery life was considered as a good option.
* We also thought about the possibility to recover energy from water flow sensor dynamics, for example with a dynamo. However, this solution was not feasible for our hardware because of the impossibility to access to the enclosed rotor in a proper way.

## Simulation
We built a simulation infrastructure on IoT-LAB, in order to provide a large scale irrigation water leakage system and to test distributed interaction between MCUs. In detail, the system scheme is tree-based, with a root node corresponding to the source MCU, intermediate nodes corresponding to fork MCUs and leaf nodes corresponding to MCUs at valve site. The communication between simulated devices is implemented using LoRaMAC, while LoRaWAN and TheThingsNetwork are used to send data to the cloud.

## Prototype
We construct a real prototype to demonstrate the working principle of the system. It is made up of a linear pipe and two MCUs located at its endopoints, with a water flow sensor for each one, together with a water source and an intermediate valve used to simulate a leakage.

Unfortunately, we found some problems working with LoRa with our chosen ESP32, even if it should be officially supported by RIOT. So, in order to overcome this issue, we decided to switch to WiFi technology only for demonstating purposes. The idea is that when LoRa issue will be hopefully solved soon our project can be adapted with minor changes. Even if we will not obiouvsly have the same performance of LoRa, the procedure of evaluation is identical.

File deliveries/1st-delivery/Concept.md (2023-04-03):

# Problem
Today irrigation is still handled in some cases with manual activation of water valves. On the other hand, watering automation is often a simple standard neither keeping into account the effective needs of the soil nor possible water leaks from watering pipes. This superficial management is leading to a huge waste of water, which is one of main causes of drought.

# Proposed solution
Our proposed solution consists of an interface through which it is possible to monitor the irrigation system. The user can know if a leakage is detected and where it is located, as well as the flow of water at the source site and the current humidity of the soil in correspondence of each solenoid valve. Another available information is the past irrigation schedule, with the relative periodical measurements of humidity of the soil (every hour). 

# Use cases 
Our system allows to do the following tasks:
* Leakages detection, quantification and localization
* Automated water flow regulation
* Water usage monitoring and management

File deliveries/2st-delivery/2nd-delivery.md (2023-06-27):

# 2nd delivery

## Comments received

* Explain how a leak is detected and why we have choosen this architecture.
* Explain the problematics about the integration of RIOT LoraWan driver and the LoraMac driver (ttn vs p2p).
* Duty cycle: asynchronicity vs synchronicity to exchange messages.
* Sensing: how to avoid data noise. Possible solution: sliding window. Compare more samplings vs one sampling with a bigger duration.

## Changes

The most important changes in this delivery are:

* The first version of the prototype.
* First considerations about the algorithms for exchange messages between nodes.
* First try to formalize energy consumption, considering the algorithms choosen.
* First experiments on IoT Lab: leakage detection on a distributed system.

## Future work

* Experiments on prototype data and on IoT Lab, focussing on energy.
* Reasoning about improvement of the first version of the prototype and energy consumption.
* Web architecture: AWS.
* Improve the documentation, showing all the reasoning behind the choices made.

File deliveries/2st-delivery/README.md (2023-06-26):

# Irrigation Water Leakage System

## People

| People | Linkedin | Github |
|--- |--- |--- |
| Riccardo Gobbato | [Linkedin](https://www.linkedin.com/in/riccardo-gobbato-380674251/) | [Github](https://github.com/RicGobs) |
| Simone Scaccia | [Linkedin](https://www.linkedin.com/in/simone-scaccia-40b631210/) | [Github](https://github.com/simonescaccia) |
| Pasquale Mocerino | [Linkedin](https://www.linkedin.com/in/pasquale-mocerino-29088b1a2/) | [Github](https://github.com/pasqualemocerino) |

## Description

Our project is designed to offer some smart functionalities to an irrigation system. Our main goal is to keep track of water usage and leakages, in order to avoid the waste of water. In detail, the system provides measurements about water flow in different locations and it detects possible water leakages through irrigation pipes, triggering a proper alarm.

[Concept](./Concept.md) provides details from the user perspective, while [Design](./Design.md) provides technical details about the project. Finally, [Evaluation](./Evaluation.md) focuses on performance issues.

## Links

[Concept](./Concept.md)\
[Design](./Design.md)\
[Evaluation](./Evaluation.md)

## Video

It will be uploaded soon.

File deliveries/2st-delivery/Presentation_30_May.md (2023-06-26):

# Problems

## Algorithms to avoid false positives on leakage detection

ack <br>
handshake <br>
syncAck <br>

## Simulation on IoT-Lab

### Goals

- Detect leakages in a distributed infrastructure.
- Use LoRa protocols to exchange messages.
- Run experiments with various algorithms to measure energy consumption using monitoring tools.

### Done

simulation-done

### Doing

simulation-doing

### To Do

simulation-todo

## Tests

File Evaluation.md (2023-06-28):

# Evaluation

## Evaluation methodology: Overall System

As a general performance evaluation of the system, we wanted to detect if a water leak occurs within 24 hours, in order to detect water leakages without tolerating more than one day of water losses. We wanted also to know wich pipe is leaking.

We used the following metrics to evaluate the performance of the system:

1. Leak is dectected within 24 hours
2. The pipe is correctly identified

## Evaluation methodology: Individual Components

We wish to evaluate the power consumption of MCUs that are not attached to a power cord, so for the FORK and the BRANCH MCUs.

+ Power supply of source site MCU is provided by a power cord, hence there are no specific constraints on power consumption.
+ MCUs at fork sites and crop site, due to the limited workload, we wish to obtain a battery life equal to the total period of irrigation.

## Algorithms Performances

### Water leak detection Algorithm Problems

Before designing a water leak detection algorithm, we focused on the dynamics of water in pipes. Since we are dealing with an irrigation system, a reasonable assumption is to consider **water in pipes under pressure**. It means that there are never empty pipes. Now, we can have two conditions, either stationary water or moving water, due to the increasing pressure at the source during irrigation time. This means that we can ignore the specific condition when doing a test, because the difference between adjacent flows will be bounded in both cases if there is no leakage, and not bounded otherwise. The detection algorithm starts from the source and propagates through the tree topology, always with the same logic for every father-child pair. The father sends water flow information to the child, which makes a proper computation and compares the obtained value with the received one, using a specific threshold. In case of leakage detection, it will communicate the leakage to the cloud through the LoRa gateway.

One of the main problems related to the test is related to synchronization, because of the delay related to transmission latency. We thought about an handshaking approach to take into account this discrepancy and to compare water flows starting the sampling process at two close moments.

1. Test propagation phase
2. Leak notification

The complexity will change depending on the number of FORKs, we have choose the topology of the Design.

The three algorithms proposed in the design phase have been tested. 

The test of the Ack algorithm has shown that there is a problem in the code (intially we thought it is caused by the use of threads in the program, after we understood is linked to the water flow sensor) and that the water flow before our system (that we consider always present) is not stable and this issue has to be solved by the synchronization algorithm.<br/>

The problem of stability of the initial water flow can be seen in the following image in which there is a segmentation of the lines of the graph. In x axis there are the samplings (3 s each )which are done one after the other in a small time (5 min max). <br/>

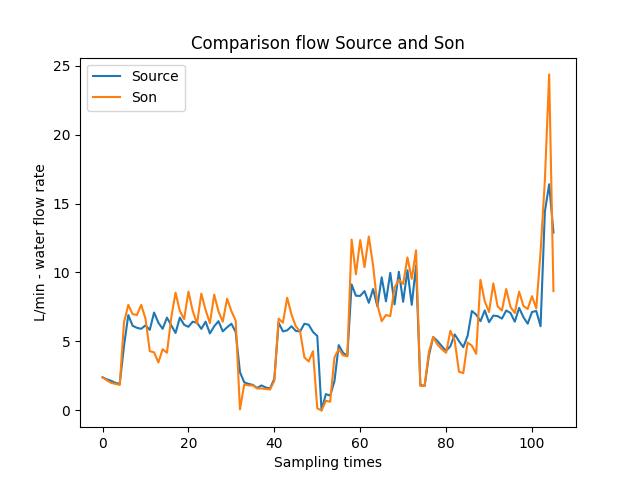
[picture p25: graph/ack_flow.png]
ack
 <br/>
About the Ack algorithm, it is possible to notice that it is good to detect a leakage but it says that the water flow of the Son is always higher than the water flow of the Source, and this can lead to error, so it is not the worst algorithm implemented.<br/>

The following image shows the test of the ack algorithm and it is possible to observ the big difference between Source and Son. Here the samplings are done in a period of a month for each graph. In the next graphs, when there is more blue line, it means there is a leakage.<br/>
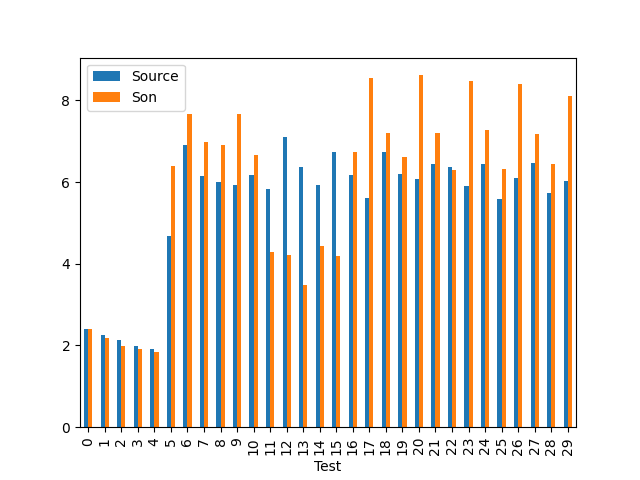
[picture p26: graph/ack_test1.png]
ack1
<br/>

About the Hanshake algorithm, it is perfect to detect the leakage and the trend of the Son higher than the Source is disappeared. There still is an error of the turbines, that we will face in the next chapter.<br/>

The following image shows the test of the Handshake algorithm and it is possible to observ a smaller difference between Source and Son. But there still is a trend in which the Son is higher than the Source.<br/>
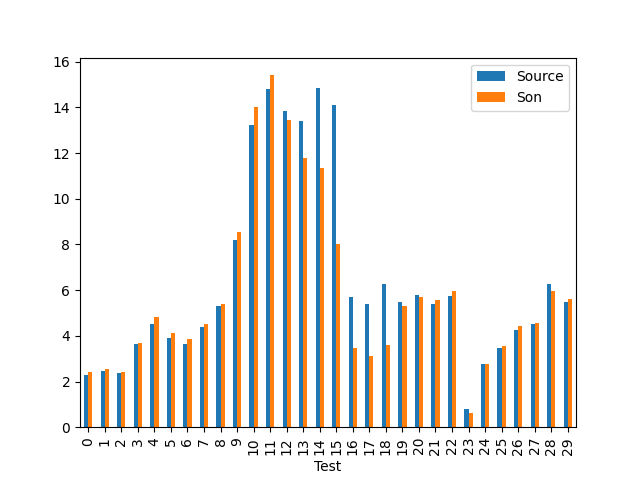
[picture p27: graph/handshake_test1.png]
h1
<br/>

In the end, about the syncAck algorithm, it is possible to see the same trend of the handshake algorithm but with one less message. There is also here the error of the turbines.<br/>

The following image shows the test of the SyncAck algorithm and it is possible to observ a smaller difference between Source and Son. Here the trend is that the Son is higher than the Source.<br/>
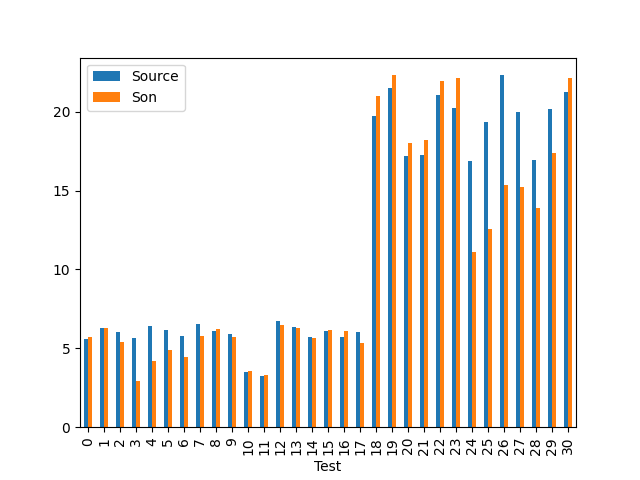
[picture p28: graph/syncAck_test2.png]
s2
<br/>

The following image shows another the test of the SyncAck algorithm, but here the trend is the opposite. This suggests a problem in the water flow sensor.<br/>
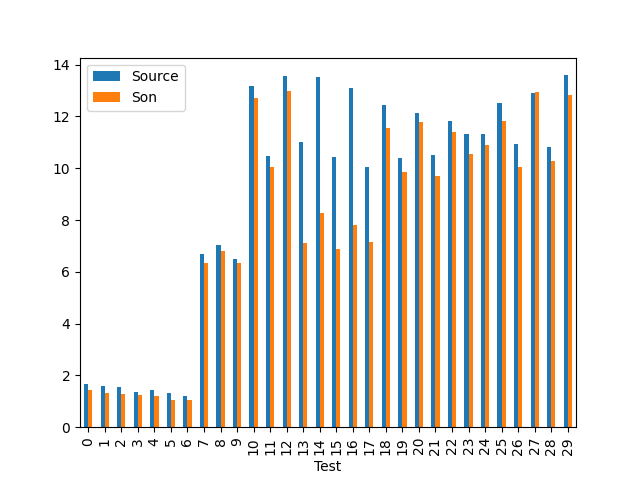
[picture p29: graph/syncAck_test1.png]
s1
<br/>

### Water leak detection Algorithm Solutions

After several tests, and using the considerations done before, we have found that one water flow sensor has some problems and detect less impulses. 

Not having other sensors, we have decided to put the best sensor in the Source and the worst in the Son, so we will have an higher Source in a NO leakage situation.

### Water leak detection Threshold

We have done some analysis to set a correct threshold in our algorithms to limit the presence of false positives and false negatives.<br/>

We have chosen the syncAck as the final algorithm because it uses one message less.
We have analysed the time of the SyncAck algorithm to understand the error that can be created and to use this values for the calucus of the energy consumption.
We have analysed that the standard deviation is high and this means that there is a large distribution of the data, in particular this means that the time taken by the messages and the code is fluctuating. Looking at the scheme, it is possible to understand the time of the messages and also the quality of the synchronization of the algorithms.<br/>
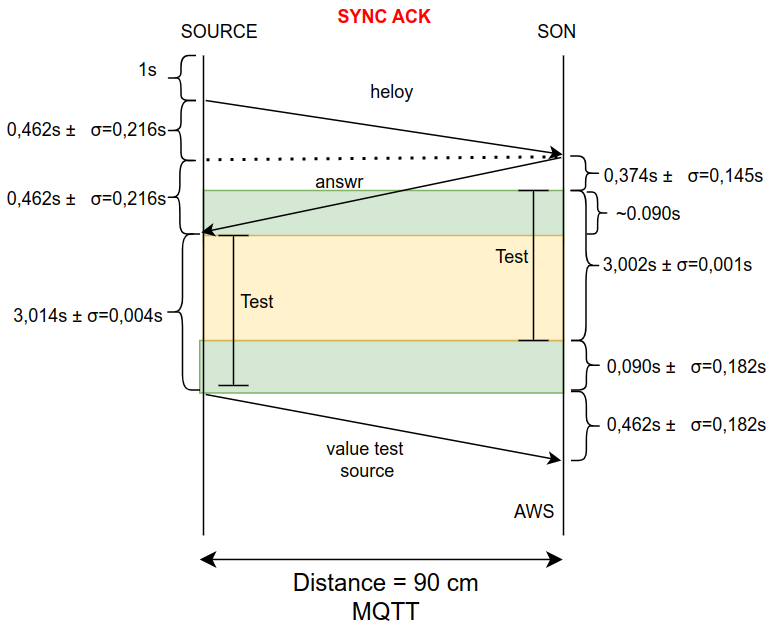
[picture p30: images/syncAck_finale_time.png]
s
<br/>
Here the messages take 0.462 s while the latency of the two samplings is 0.552 s (time in the Son between the end of the test and the arrival of the value of the Source). This means that the Source has ended the test 0.090 s before the Son. So Son and Source have an error of synchronization of 0.090 s. 

<br/>**Difference**<br/>
To find the error of the algorithm we have to decide the time of testing: now is 3s but if we increase it, the influence of the error derived by the synchronization problem is less.The proportion is 0.090s : (TimeSampling) = x : 100. The FlowMax is 30 l/min.

With influence we mean: **$FlowMax \cdot \frac{0.090 \cdot 100}{TimeSampling}$**:

We have analysed three times of testing. 
* TimeSampling of 3s: 3% of influence, 0.90 L/min difference of water flow rate
* TimeSampling of 5s: 1.8% of influence 0.54 L/min difference of water flow rate
* TimeSampling of 10s: 0.9% of influence 0.27 L/min difference of water flow rate

So we take 10s of sampling time to limit the possible error. We do not increase more the sampling time because there will be a trade off with the energy.

Now it is important to discuss this values. The 0.27 L/min is the **possible difference of L/min** between the Source and the Son. This is the worst case scenario but it is important to analyse the algoritmic error in the worst case.<br/> 

It is important to focus also on the instrumental error.

In the last days, we have also thought that this holds also for the time of the handshake algorithm. But we have not checked sperimentally.

In conclusion, because we have done this observation lately, at this point we have choose the **SyncAck algorithm** because it uses one message less. We will see after that the handshake algorithm is not too much more consuming than the SyncAck. <br/>
Then we have choose a **sampling time of 10 seconds** to have a longer analysis of the environment and to reduce the algorithmin error.

We have done another consideration.

The water enter in the first turbine, then it has to flow on the pipeline and arrives in the second turbine. So if the water is too muxh slower than the time of latency, the water of the first turbine taken by the sampling is different from the water of the sampling of the Son. It is important to analyse the speed of the water and the time from the Source to the Son. In particular in our case, the water takes:

* diameter of pipeline: 0.015m
* area of circle: 0.00018 $m^{2}$
* water flow of water max (worst case): 30 L/min = 0.5 L/s
* distance: 0.9 m
  
$$speed of water= \frac{0.5 \cdot 10^{-3}}{0.00018} = 2.83 \frac{m}{s}$$ 
$$time = \frac{2.83}{0.9} = 0.32 s$$

Meanwhile the water is complete different for a distance of:
$$time = \frac{2.83}{distance} = 10 s$$
$$distance = 2.83 \cdot 10s = 28.3 m$$

With this observation, to deal with the algorithmic error, we have to assume a constant water flow rate before the Source.  .

### Turbine error

Another significant error of the architecture is the instrumental error of the water flow sensor. Because of we have not another turbine with the correct value of the water flow or other instruments, we have run the system for several tests and we have analysed the difference between the values of Source and Son. We have observed the difference because the water flow before our application is not costant (decided by the public pipeline). It is important to observ that this error is influenced by the algorithmic error too. We have taken in consideration also the handshake algorithm.

The following image shows the test of the Handshake algorithm with the best water flow sensor in the Son.
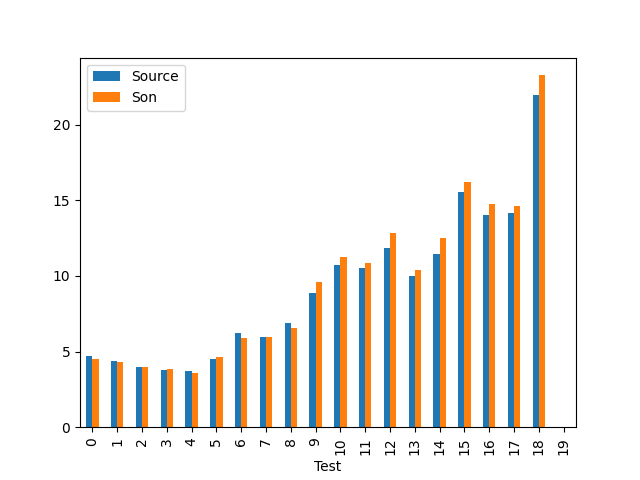
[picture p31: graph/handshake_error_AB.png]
h3AB
<br/>

The following image shows the test of the Handshake algorithm with the best water flow sensor in the Source.
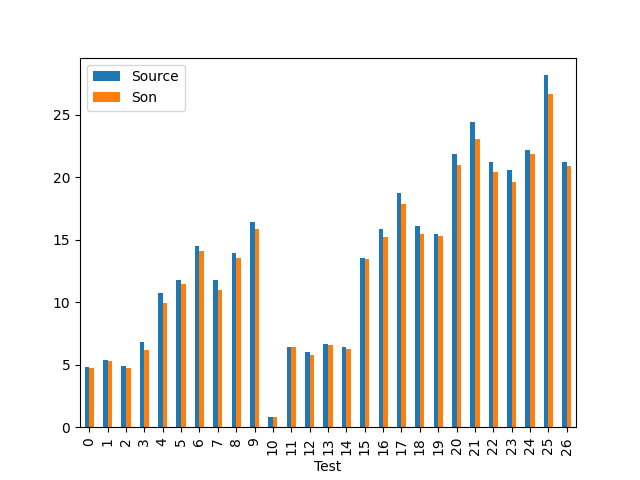
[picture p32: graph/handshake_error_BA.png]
h3BA
<br/>

The following image shows the test of the SyncAck algorithm with the best water flow sensor in the Son.
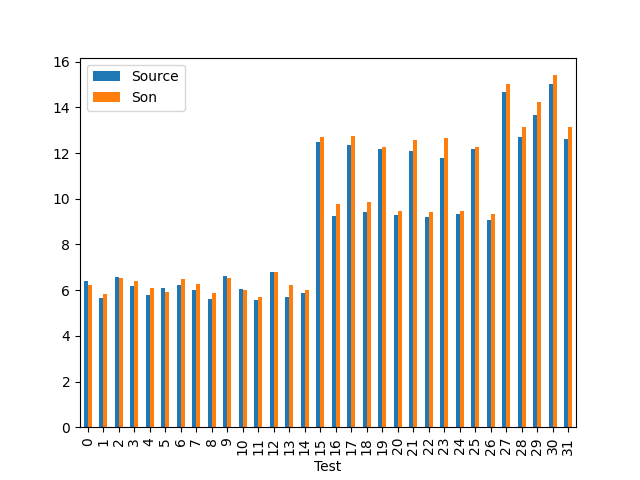
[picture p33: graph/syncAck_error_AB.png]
s3AB
<br/>

The following image shows the test of the SyncAck algorithm with the best water flow sensor in the Source.
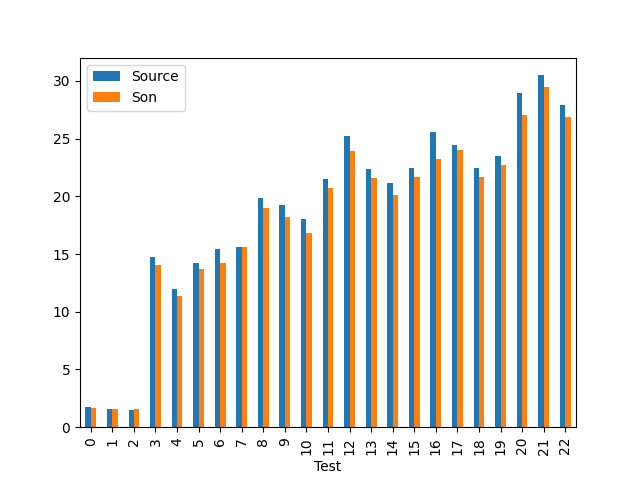
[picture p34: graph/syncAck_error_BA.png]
s3BA
<br/>

The system is proned to have the Son with an higher water flow value, if you put turbine A before turbine B, but this happens because the turbine A is less efficient. <br/>
For our prototype and with a distance of 90cm between the nodes, based on the consideration of the several approssimations, We have initially fought to put a threshold of 1 L/min, but then we have done more considerations.<br/>
We have first set a fixed scenario: 
* turbine B = Source 
* turbine A = Son
Then, we have done a lot of tests changing time of sampling and water flow rate. <br/>
With the analysis of the algorithmic error done before, we thought that an higher sampling was more accurate but the data has not shown this. The tests are done with the use of the syncAck, the table below shows the error rate for the different situation: <br/>

|flow x time| 3s | 5s | 9s |
|--- |--- |--- |--- |
| 0-30 L/min | 0.84 L/min | 0.49 L/min | 0.74 L/min |
| 0-10 L/min | 0.14 L/min | 0.29 L/min | 0.13 L/min |
| 10-20 L/min | 0.58 L/min | 0.67 L/min | 0.76 L/min |
| 20-30 L/min | 1.11 L/min | 1.16 L/min | 1.10 L/min |

The first line is not relevant because there are not enough data and are not distributed well.<br/>
Then, it is possible to note that the difference is not caused by the different time of sampling, but by the different water flow rate: this lead to say that the main error is the error of the turbines and not the error of the algorithm. <br/>
So, we can decide to use the syncAck algorithm knowing that it uses one message less, not keeping in mind the algorithmic error. <br/>





<br/>
We have analysed these data to fix a threshold for the detection of the leakages, and we have done the mean of **(flowSource-flowSon)x100/flowSource** %:

* 3s -> 4,29%
* 5s -> 6,34%
* 9s (done 9s and not 10s because of a problem of MQTT) -> 4,30% <br/>

We have decide to take 10s for the sampling and this will be similar to 9s result, so in this situation we can put a fixed threshold of > 2L/min or dynamic threshold flowSource-flowSon > 5% flowSource L/min. The dynamic threshold is more efficient because it is more accurate in the lower water flow rate. We have done some sperimental test but the system was proned to false positives. So below there are our conclusions.

#### Conclusions on the threshold

Finally, for the threshold, we will give this observation:
1. We did some tests and considering the average, we observed that in a No leakage situation there is a 5% difference between Source and Son, due to the error of a turbine (instrumental error).
2. We then observed that, based on the changes in the flow before the source (therefore on the stability of the flow rate of the pipeline), there may be an average possible error of 0.9%, due to the algorithmic error.
3. We have tried to apply the 5% threshold but experimentally we found too many false positives. We tried 7% and 10%. We have judged that 10% is acceptable.
4. Finally considering that the turbines in a NO leakage situation have an unexpected 5% error; assuming that there is not the same problem for the future system, we will have a threshold of 5%.
5. There is the problem of the speed of the water, in our case it takes 0.32 s to go from Source to Son. This gives a final 4.1% of possible algorithmic error.
6. In general, the threshold will depend on the properties of the particular system (distance of nodes, width of pipe, error of turbine).
7. Why did it happen? 
* First of all we have done many approximations.
* The standard deviation is high and we have understood it as an unreliability of the mean. 
* Finally, the conduct of the test affects the result: the position of the cell phone and the turbines varies the times of the messages (and therefore the algorithmic error).
* The stability of water flow rate before the Source has been probably good during the training of the threshold and bad in the test.

### Energy consumption

#### Duty cycle

Our requirement is not to tolerate a water loss of more than one day, so we wish to detect a leakage within 24 hours. Now, since the leakage is an unpredictable event, we cannot define a precise strategy apriori, but we want to indentify the best one in order to minimize power consumption. We compute this strategy analitically. In the first following analysis, we do not make any assumption about synchronization of nodes. Firstly, for simplicity, we focus on a simple father-child pair, since the same reasoning holds for every adjacent pair of nodes of the tree topology. Now, we define x as the send rate (msg/day) of the father, so the number of messages sent per day, and y as the total listen interval of the child (in hours/day). 

dutycycle

In order to be sure to correctly listen to at least one message in one day, y should be equal to (24/x + epsilon) hours/day, where epsilon is a neglectable time interval if compared with 24/x hours. Computing the energy consumption, there are three contributions, one related to the sender, one to the receiver and one to the exchange of messages linked to the leakage detection algorithm, so both for synchronization and test. This last component can be omitted in our considerations because it is not relevant for our estimation of x, which we wish to know. So, the energy consumption to minimize is given by:

$$E(x,y) = E(x) + E(y) + E(algorithm) \approx E(x) + E(y)$$

The two components are: 
$$E(x) = (P_{trans} \cdot t_{trans}) \cdot x + (P_{on} \cdot t_{on}) \cdot x +(P_{off} \cdot t_{off}) \cdot x$$

$$E(y) = P_{listen} \cdot y + P_{on} \cdot t_{on} + P_{off} \cdot t_{off}$$

Our analysis is hence focused on finding the integer value of x (number of messages per day of the father) such that the energy consumption is minimized. The listen time of the child will depends on x value. 

In order to estimate the value of x to minimize energy consumption, we analysed some graphs from IoT-Lab simulation.
First, we considered the transmission parameters of LoRa:

trans_energy

The transmission time and power are:
$$P_{trans} = 0.455 W$$ 
$$t_{trans} = (0.17 - 0.080) s = 0.090 s = 2.5 \cdot 10^{-5} h$$

The transmission effectively starts at 0.085 seconds, however, we considered all the interval time where some variation is revealed. In this way we also considered the contribution of the energy for switching on and off the transmission. Hence:

$$E(x) = (P_{trans} \cdot t_{trans}) \cdot x + (P_{on} \cdot t_{on}) \cdot x +(P_{off} \cdot t_{off}) \cdot x$$
$$E(x) \approx (P_{trans} \cdot t_{trans}) \cdot x = (0.455 W) \cdot (2.5 \cdot 10^{-5} h) \cdot x = 1.14 \cdot 10^{-5} Wh \cdot x$$

The power consumption due to listening can be found analysing the listening process:

listen_energy

So the average listening power is:

$$P_{listen} = 0.325 W$$

While the average sleeping power, useful for further considerations, is:

$$P_{sleep} = 0.28 W$$

Also, for this case, we do not consider the small constributions due to the a single on and a single off switching, so:

$$E(y) = P_{listen} \cdot y + P_{on} \cdot t_{on} + P_{off} \cdot t_{off}$$
$$E(y) \approx P_{listen} \cdot y $$

So, the final analysis is on the function:

$$E(x) + E(y) = 1.14 \cdot 10^{-5} \cdot x + (0.325 \cdot \frac{24}{x}) $$

So the function to minimize is:

$$f(x) = 1.14 \cdot 10^{-5} \cdot x + \frac{7.8}{x}$$

The minimum of the function, considering the domain of $$x \geq 1$$
because we have to send at least one message per day. Solving the function analytically, we found a global minimum for:

$$x \approx 828$$

So the send rate of the father should be 828 messages/day, hence the listen time will be:

$$y = \frac{24}{x} = \frac{24}{828} \approx 0.029 \frac{hours}{day} \approx 1.74 \frac{min}{day} \approx 104 \frac{s}{day}$$

#### Estimation of system duration

To analyse the duration of our system, we must also consider other energy contributions, mainly the measurement, the sleep and the cloud transmission energy consumptions. We considered the daily worst case, so the case of an intermediate node that measures twice and sends data to child 828 times, listens for 104 seconds, receives data from the father once after algorithm execution and sends once to the cloud the difference with father water flow. In our analysis,

$$E_{cloud} \approx E_{trans} = 1.14 \cdot 10^{-5} Wh$$

The energy of measurement has been computed from the prototype, since water flow values are simply simulated and not measured in IoT-Lab simulation. Hence:

$$E_{measure} = (P_{sensor} + P_{active}) * t_{sampling} = [(0.05W) + (0.28 W)] \cdot (10 s) = (0.33 W) \cdot (2.78 * 10^{-3}) = 9.174 \cdot 10^{-4} Wh$$

Daily energy consumption is computed as:

$$E_{tot} = 2 \cdot E_{measure} + E_{trans}\cdot 828 + 2 \cdot E_{trans} + E_{cloud} + P_{listen} \cdot (0.029h) + P_{sleep} \cdot (24 - 0.029) h$$

$$E_{tot} = 2 \cdot (9.174 \cdot 10^{-4} Wh) + (1.14 \cdot 10^{-5} Wh) \cdot 828 + 3 \cdot (1.14 \cdot 10^{-5} Wh) + (0.325 W) \cdot (0.029 h) + (0.28 W) \cdot (23.971 h)$$
$$E_{tot} \approx (1.835 \cdot 10^{-3} Wh) + (9.47 \cdot 10^{-3} Wh) + (9.425 \cdot 10^{-3} Wh) + (6.71 Wh) \approx 6.73 Wh $$

So, for a year:

$$E_{tot} = E_{tot} \cdot 365 = 2456.71 Wh$$

Here, we have used the power of the sleep monitored from Iot-Lab and indeed the consumption is huge, but in the datasheet of our [Heltec ESP32 Lora v2](https://heltec.org/project/wifi-lora-32/) it is reported the power consumption of the Deep Sleep Mode:
$$P_{deepSleep} \approx 800µA \cdot 5V =  0.004 W $$
$$E_{tot} \approx (1.835 \cdot 10^{-3} Wh) + (9.47 \cdot 10^{-3} Wh) + (9.425 \cdot 10^{-3} Wh) + (0.096 Wh) \approx 0.117 Wh $$

So, for a year:

$$E_{tot} = E_{tot} \cdot 365 = 42.61 Wh$$

Also here the consumption is too huge, because the time of listening is too high. So we propose another approach.

### Drift rate clock

Starting from the output of the chapter before, we use another approach with node synchronization.

Now only one message per day is needed, since node are synchronized, and listening time is reduced. In the context of each pair, for each node there will be a situation in which it will be the passive one (waiting in listening) and another situation in which it will be active (send the message for starting the test). As before, we consider the worst case, in which a node is both passive and active. We use Deep sleep mode. The drift rate for ESP32 is 1.7 sec per day. Assuming a resynchronization for each day, we need to set a listening time per day such that the drift rate over the day is not a problem. An acceptable solution is 10 seconds/day.

$$E_{tot} = 2 \cdot E_{measure} + E_{trans}\cdot 1 + 2 \cdot E_{trans} + E_{cloud} + P_{listen} \cdot (2.76 \cdot 10^{-3}h) + P_{deepSleep} \cdot (23.99) h$$

$$E_{tot} = 2 \cdot (9.174 \cdot 10^{-4} Wh) + (1.14 \cdot 10^{-5} Wh) \cdot 1 + 3 \cdot (1.14 \cdot 10^{-5} Wh) + (0.325 W) \cdot (2.76 \cdot 10^{-3}h) + (0.004 W) \cdot (23.99 h)$$
$$E_{tot} \approx (1.835 \cdot 10^{-3} Wh) + (4.56 \cdot 10^{-5} Wh) + (8.97 \cdot 10^{-4} Wh) + (0.096 Wh) \approx 0.099 Wh $$

So, for a year:

$$E_{tot} = E_{tot} \cdot 365 \approx 36 Wh$$

In this situation, we would use a $5000mAh$ battery (for example, a phone battery), replacing it every 6 months

So, we noticed that the energy consumption bottleneck is given by the energy consumed during sleep time. However, in the official documentation of [ESP32 Series](https://www.espressif.com/sites/default/files/documentation/esp32_datasheet_en.pdf), we found another value for the Deep sleep mode:

$$P_{deepSleep} \approx 150µA \cdot 5V =  0.00075 W $$
$$E_{tot} \approx (1.835 \cdot 10^{-3} Wh) + (4.56 \cdot 10^{-5} Wh) + (8.97 \cdot 10^{-4} Wh) + (0.018 Wh) \approx 0.021 Wh $$
So, for a year:

$$E_{tot} = E_{tot} \cdot 365 = 7.58 Wh$$

Now, with a battery of $2500 mAh$, we can power the device for at least one year, that is our user requirement.

### Water flow sensor for energy harvesting

Our water flow sensor can not create energy for our batteries because the electronic part is not connected to the turbine, it is only connected to the Hall Effect sensor.

To allow energy harvesting, we should have an alternator connected to the turbine to transform the mechanical energy into electrical energy.

A possible solution for the energy harvesting can be found [here](https://www.ebay.it/itm/322724692568) with the [tutorial](https://www.youtube.com/watch?v=mtMO3VmCmiQ) of the turbine.

We should for example connect this type of turbine called micro hydro water turbine generator to our water flow sensor.
 <br/>

We have analysed if there is the possibility to charge the device using this turbine and it is feasible: 
1. From previous analysis, ESP32 and water flow sensor are powered with $0.33 W$.
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

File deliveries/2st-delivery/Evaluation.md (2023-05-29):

# Evaluation

## Evaluation methodology: Overall System

### During the development of the project

General performance evaluation of the system:
We want to detect if a water leak occur within 24h, in order to detect water leakages without tolerating more than one day of water losses. We want also to know wich pipe is leaking.

We will use the following metrics to evaluate the performance of the system:

1. Leak is dectected within 24h
2. The pipe is correctly identified

### When the first complete version of the system will be ready for use

We want to detect if a water leak occur within 24h, in order to detect water leakages without tolerating more than one day of water losses. We want also to know wich pipe is leaking, providing information about the quantity of water leakage in a second.

1. Leak is dectected within 24h
2. The pipe is correctly identified
3. The quantity of water leaked per second with an accuracy of 95% (sensor precision error)

## Evaluation methodology: Individual Components

We wish to evaluate the power consumption of MCUs that are not attached to a power cord, so for the FORK and the BRANCH MCUs.

+ Power supply of source site MCU is provided by a power cord, hence there are no specific constraints on power consumption.
+ MCUs at fork sites and crop site, due to the limited workload, we wish to obtain a battery life equal to the total period of irrigation.

## Network Technologies Performances

+ Latency (s)
+ Throughput (bit/s)

## Algorithms Performances

### Water leak detection Algorithm
Before designing a water leak detection algorithm, we focused on the dynamics of water in pipes. Since we are dealing with an irrigation system, a reasonable assumption is to consider water in pipes under pressure. It means that there are never empty pipes. Now, we can have two conditions, either stationary water or moving water, due to the increasing pressure at the source during irrigation time. This means that we can ignore the specific condition when doing a test, because the difference between adjacent flows will be bounded in both cases if there is no leakage, and not bounded otherwise. The detection algorithm starts from the source and propagates through the tree topology, always with the same logic for every father-child pair. The father sends water flow information to the child, which makes a proper computation and compares the obtained value with the received one, using a specific threshold. In case of leakage detection, it will communicate the leakage to the cloud through the LoRa gateway.

One of the main problems related to the test is related to synchronization, because of the delay related to transmission latency. We thought about an handshaking approach to take into account this discrepancy and to compare water flows starting the sampling process at two close moments.

1. Test propagation phase
2. Leak notification

The complexity will change depending on the number of FORKs, and we will compare variuous topologies in order to find the best one.

### Energy consumption
Our requirement is not to tolerate a water loss of more than one day, so we wish to detect a leakage within 24 h. Now, since the leakage is an unpredictable event, we cannot define a precise strategy apriori, but we want to indentify the best one in order to minimize power consumption. We compute this strategy analitically. Firstly, for simplicity, we focus on a simple father-child pair, since the same reasoning holds for every adjacent pair of nodes of the tree topology. Now, we define x as the send rate (msg/day) of the father, so the number of messages sent per day, and y as the total listen interval of the child (in hours/day). In order to be sure to correctly listen to at least one message in one day, y should be equal to (24/x + epsilon) hours/day, where epsilon is a neglectable time interval if compared with 24/x hours. Computing the energy consumption, there are three contributions, one related to the sender, one to the receiver and one to the exchange of messages linked to the leakage detection algorithm, so both for synchronization and test. This last component can be omitted in our considerations because it is not influenced by the choice of x, which we wish to know. So, the total energy consumption is given by:

$$E(x,y) = E(x) + E(y) + E(algorithm) \approx E(x) + E(y)$$

The two components are: 
$$E(x) = P_{trans} \cdot t_{trans} + (P_{on} \cdot t_{on}) \cdot x +(P_{off} \cdot t_{off}) \cdot x$$

$$E(y) = P_{listen} \cdot y + P_{on} \cdot t_{on} + P_{off} \cdot t_{off}$$

Our analysis is hence focused on finding the integer value of x (number of messages per day of the father) such that the total energy consumption is minimized. The listen time of the child will depends on x value. 

### Monitoring of the water flow Algorithm

From the CHIEF MCUs, send periodically a message to the cloud to update the water flow consumed.
Performances depends on the latency between the cloud and the MCUs.

## Water flow sensor for energy harvesting
This water flow sensor can not create energy for our batteries beacuse the electronic part is not connected to the turbine, it is only connected to the Hall Effect sensor.

To allow the harvesting of the energy, we should have an alternator connected to the turbine to transform the mechanical energy into electrical energy.

A possible solution for the energy harvesting is here: https://www.ebay.it/itm/322724692568 with the tutorial of the turbine https://www.youtube.com/watch?v=mtMO3VmCmiQ .

We should for example connect this type of turbine called micro hydro water turbine generator to our water flow sensor.

## Response Time Performances

The response time between CHIEF, FORKs and BRANCHEs depends on the distance between the MCUs, so it depends on the topology of the irrigation system.

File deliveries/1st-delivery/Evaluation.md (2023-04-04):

# Evaluation

## Evaluation methodology: Overall System

### During the development of the project

General performance evaluation of the system:
We want to detect if a water leak occur within 24h, in order to detect water leakages without tolerating more than one day of water losses. We want also to know wich pipe is leaking.

We will use the following metrics to evaluate the performance of the system:

1. Leak is dectected within 24h
2. The pipe is correctly identified

### When the first complete version of the system will be ready for use

We want to detect if a water leak occur within 24h, in order to detect water leakages without tolerating more than one day of water losses. We want also to know wich pipe is leaking, providing information about the quantity of water leakage in a second.

1. Leak is dectected within 24h
2. The pipe is correctly identified
3. The quantity of water leaked per second with an accuracy of 95% (sensor precision error)

## Evaluation methodology: Individual Components

We wish to evaluate the power consumption of MCUs that are not attached to a power cord, so for the FORK and the BRANCH MCUs.

+ Power supply of source site MCU is provided by a power cord, hence there are no specific constraints on power consumption.
+ MCUs at fork sites, due to the limited workload, we wish to obtain a battery life equal to the total period of irrigation.
+ For crop site MCUs we may obtain a battery life at least equal to the growing period of the related crop.

## Network Technologies Performances

+ Latency (s)
+ Throughput (bit/s)

## Algorithms Performances

### Water leak detection Algorithm:

1. Test propagation phase: Close all the solenoid valves

+ One message from the CHIEF to the FORK childs
+ One message from the FORK to the FORK childs
+ One message from the FORK to the BRANCH childs

2. Detection phase: Check if the FORK recognize a water flow

+ One message from the BRANCH to the FORK parent
+ One message from the FORK to the FORK parent
+ One message from the FORK to the CHIEF parent

3. Continue working phase: Test ended, continue working as usual

+ One message from the CHIEF to the FORK childs
+ One message from the FORK to the FORK childs
+ One message from the FORK to the BRANCH childs

4. If a leak is detected, the system will send a message to the cloud to notify the user

We will evaluate the number of messages sent by the protocol and the time needed to complete the algorithm.
The complexity will change depending on the number of FORKs, and we will compare variuous topologies in order to find the best one.

### Irrigation Algorithm:

    def automated_irrigation(humidity_threshold):

        humidity_level = get_humidity() // From soil humidity sensor
    
        if (humidity_level < humidity_threshold):
            open()  // Open signal to solenoid valve
        
            while (humidity_level < humidity_threshold):
                wait(time_interval) // Wait some time to make humidity change
                humidity_level = get_humidity()
            
            close()  // Close signal to solenoid valve

The algorithm perfomance depends on the capacity of the soil to absorb water, and on the responsivness of the humidity sensor. 

### Management of the water flow Algorithm:

From the cloud, send a message to the BRANCH MCUs to close the solenoid valves

Performances depends on the latency between the cloud and the MCUs.

### Monitoring of the water flow Algorithm:

From the CHIEF MCUs, send periodically a message to the cloud to update the water flow consumed

Performances depends on the latency between the cloud and the MCUs.

## Response Time Performances

The response time between CHIEF, FORKs and BRANCHEs depends on the distance between the MCUs, so it depends on the topology of the irrigation system.

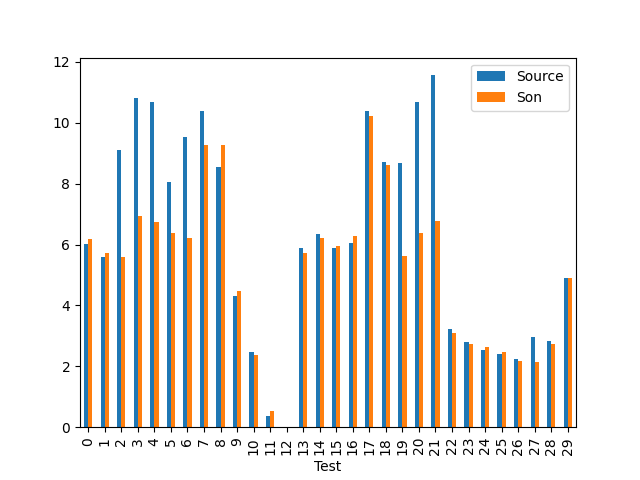
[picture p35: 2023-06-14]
graph/handshake_test2.png

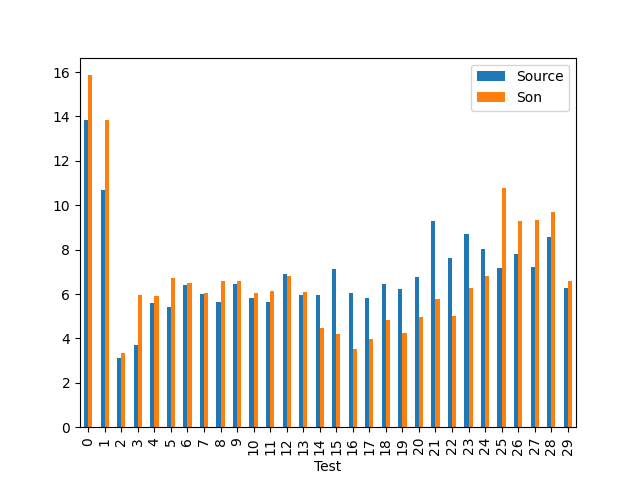
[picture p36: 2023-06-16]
graph/ack_test3.png

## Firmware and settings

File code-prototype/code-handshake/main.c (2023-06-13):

#include <string.h>
#include <stdbool.h>
#include <stdlib.h>
#include "timex.h"
#include "xtimer.h"
#include "ztimer.h"
#include "paho_mqtt.h"
#include "MQTTClient.h"
#include "stdio.h"
#include "periph/gpio.h"
#include "periph/adc.h"
#include "thread.h"
#include "analog_util.h"

int board=0; //  0 -> padre, che vien settato così  -----  1 -> figlio viene settato prima a 0 e poi cambia, dopo aver avuto conversazione precedente

#define MAIN_QUEUE_SIZE     (8)

#define BUF_SIZE                        1024
#define MQTT_VERSION_v311               4       /* MQTT v3.1.1 version is 4 */
#define COMMAND_TIMEOUT_MS              4000

#ifndef DEFAULT_MQTT_CLIENT_ID
#define DEFAULT_MQTT_CLIENT_ID          ""
#endif

#ifndef DEFAULT_MQTT_USER
#define DEFAULT_MQTT_USER               ""
#endif

#ifndef DEFAULT_MQTT_PWD
#define DEFAULT_MQTT_PWD                ""
#endif

/**
 * @brief Default MQTT port
 */
#define DEFAULT_MQTT_PORT               1883
#define DEFAULT_IP                      "192.168.92.168"
#define DEFAULT_TOPIC_AWS               "home"
char* DEFAULT_TOPIC_SUB; //subscribe
char* DEFAULT_TOPIC_PUBLISH; //publish

//#define DEFAULT_TOPIC_SUB               "publish" //subscribe
//char* DEFAULT_TOPIC_PUBLISH = "subscribe" //publish

/**
 * @brief Keepalive timeout in seconds
 */
#define DEFAULT_KEEPALIVE_SEC           10

#ifndef MAX_LEN_TOPIC
#define MAX_LEN_TOPIC                   100
#endif

#ifndef MAX_TOPICS
#define MAX_TOPICS                      4
#endif

#define IS_CLEAN_SESSION                1
#define IS_RETAINED_MSG                 0

static MQTTClient client;
static Network network;

static unsigned char buf[BUF_SIZE];
static unsigned char readbuf[BUF_SIZE];

char stack_led[THREAD_STACKSIZE_MAIN];
kernel_pid_t thread_led;

char stack_buzzer[THREAD_STACKSIZE_MAIN];
kernel_pid_t thread_buzzer;

char water_sensor_stack[THREAD_STACKSIZE_MAIN];
kernel_pid_t water_sensor_thread;

char publish_stack[THREAD_STACKSIZE_MAIN];
kernel_pid_t publish_thread_aws;

char publish_stack_node[THREAD_STACKSIZE_MAIN];
kernel_pid_t publish_thread_node;

gpio_t LED_PIN = GPIO_PIN(0, 2); //pin2
#define LED_PIN_NUMBER 2

gpio_t BUZZER_PIN = GPIO_PIN(0, 15); //pin23
#define BUZZER_PIN_NUMBER 15

#define WATER_FLOW ADC_LINE(0)
#define ADC_RES ADC_RES_12BIT

#define SECONDS 1*US_PER_SEC //regulator for water_flow_rate formula
#define SAMPLING 3*US_PER_SEC //duration time of sampling
#define TESTING 2*US_PER_SEC
#define DAILY_PERIODIC 8*US_PER_SEC //periodic time of sampling (daily or every 6 hours)
#define ANSWER_AGAIN_PERIODIC 3*US_PER_SEC //again time if son is sleeping
#define NO_WATER_AGAIN_PERIODIC 8*US_PER_SEC //again time if there is not water

xtimer_ticks32_t sample_time_now;
xtimer_ticks32_t sample_time_end;
xtimer_ticks32_t sample_time_diff;
xtimer_ticks32_t periodic_time;

xtimer_ticks32_t time_s0_source;
xtimer_ticks32_t time_s1_source;
xtimer_ticks32_t time_s2_source;
xtimer_ticks32_t time_s0_son;
xtimer_ticks32_t time_s1_son;
xtimer_ticks32_t time_s2_son;

char* mex; //for received messages

int ret = -1;
char message[200];
float water_flow_rate_other=0.0;
float water_flow_rate=0.0;
float water_flow_diff=0.0;
float total_quantity=0.0;

int answer=0;
int work=0;

char* message_on_aws;
char* value_message_on_received;
//sudo BOARD=esp32-heltec-lora32-v2 BUILD_IN_DOCKER=1 DOCKER="sudo docker" PORT=/dev/ttyUSB0 make flash term

/*
We are in the same situation of YF-S201 water flow sensor - 30L/min

l_hour = (flow_frequency * 60 / 7.5)
every liter of water that flows, the Hall Sensor outputs 450 pulses. 

V_total(L) = N* 1/450(L) 

the total volume of fluid flowing through the water flow sensor is equal to the water flow rate(Q - unit L/s) multiplied by time t(unit s) .
V_total(L) = Q(L/s)*t(s) 

N* 1/450 = Q(L/s)*t(s) 
N/t = 450 * Q(L/s) 

f = 450*Q(L/s); 
Q(L/s) = f/450; 
Q(L/min) = f*60/450 = f/7.5 
Q(L/hour) = f*60*60/450 = f*60 /7.5 

l_hour = (flow_frequency * 60 / 7.5)


LEGGERE: https://wiki.seeedstudio.com/Water-Flow-Sensor/#:~:text=Water%20flow%20sensor%20consists%20of,outputs%20the%20corresponding%20pulse%20signal.


SU AMAZON ->  1L = 596 impulsi ----- https://www.amazon.it/dp/B079QYRQT5?psc=1&ref=ppx_yo2ov_dt_b_product_details
K=541,3307 [Impulsi/Litro] con errore di +-1% ma anche così 
USIAMO QUESTA
*/

static int connect(void)
{

    /* ensure client isn't connected in case of a new connection */
    if (client.isconnected) {
        printf("mqtt_example: client already connected, disconnecting it\n");
        MQTTDisconnect(&client);
        NetworkDisconnect(&network);
    }

    MQTTPacket_connectData data = MQTTPacket_connectData_initializer;
    data.MQTTVersion = MQTT_VERSION_v311;

    data.clientID.cstring = DEFAULT_MQTT_CLIENT_ID;
    data.username.cstring = DEFAULT_MQTT_USER;
    data.password.cstring = DEFAULT_MQTT_PWD;
    data.keepAliveInterval = DEFAULT_KEEPALIVE_SEC;
    data.cleansession = IS_CLEAN_SESSION;
    data.willFlag = 0;

    printf("mqtt_example: Connecting to MQTT Broker from %s %d\n",
            DEFAULT_IP, DEFAULT_MQTT_PORT);
    printf("mqtt_example: Trying to connect to %s, port: %d\n",
            DEFAULT_IP, DEFAULT_MQTT_PORT);
    ret = NetworkConnect(&network, DEFAULT_IP, DEFAULT_MQTT_PORT);
    if (ret < 0) {
        printf("mqtt_example: Unable to connect\n");
        return ret;
    }

    printf("user:%s clientId:%s password:%s\n", data.username.cstring,
             data.clientID.cstring, data.password.cstring);
    ret = MQTTConnect(&client, &data);
    if (ret < 0) {
        printf("mqtt_example: Unable to connect client %d\n", ret);
        return ret;
    }
    else {
        printf("mqtt_example: Connection successfully\n");
    }

    return (ret > 0) ? 0 : 1;
}

/*
void* led(void* arg){
    while(1){
        printf("Set led to HIGH \n");
        gpio_set(LED_PIN);
        xtimer_sleep(2);
        printf("Set led to LOW \n");
        gpio_clear(LED_PIN);
        xtimer_sleep(2);
        if (fire==0){
            thread_sleep();
        }
    }    
}

void* buzzer(void* arg){
    while(1){
        printf("Set buzzer to HIGH \n");
        gpio_set(BUZZER_PIN); 
        xtimer_sleep(2);
        printf("Set buzzer to LOW \n");
        gpio_clear(BUZZER_PIN);
        xtimer_sleep(2);  
        if (fire==0){
            thread_sleep();
        }
    }    
}
*/
void* publish_on_aws(void* arg){
    while(1){
        enum QoS qos = QOS2;
        char* topic=DEFAULT_TOPIC_AWS;
        MQTTMessage message;
        message.qos = qos;
        message.retained = IS_RETAINED_MSG;
        message.payload = message_on_aws;
        message.payloadlen = strlen(message.payload);

        int rc;
        if ((rc = MQTTPublish(&client, topic, &message)) < 0) {
            printf("mqtt_example: Unable to publish (%d)\n", rc);
        }
        else {
            printf("mqtt_example: Message (%s) has been published to topic %s"
            "with QOS %d\n",
            (char *)message.payload, topic, (int)message.qos);
        }
        thread_sleep();
    }
    return 0;
}

static int publish(char* mex){
    enum QoS qos = QOS2;
    char* topic=DEFAULT_TOPIC_PUBLISH;
    MQTTMessage message;
    message.qos = qos;
    message.retained = IS_RETAINED_MSG;
    message.payload = mex;
    message.payloadlen = strlen(message.payload);

    int rc;
    if ((rc = MQTTPublish(&client, topic, &message)) < 0) {
        printf("mqtt_example: Unable to publish (%d)\n", rc);
    }
    else {
        printf("mqtt_example: Message (%s) has been published to topic %s"
         "with QOS %d\n",
        (char *)message.payload, topic, (int)message.qos);
    }
    return 0;
}

void* publish_on_node(void* arg){
    while(1){
        enum QoS qos = QOS2;
        char* topic=DEFAULT_TOPIC_PUBLISH;
        MQTTMessage message;
        message.qos = qos;
        message.retained = IS_RETAINED_MSG;
        message.payload = value_message_on_received;
        message.payloadlen = strlen(message.payload);

        int rc;
        if ((rc = MQTTPublish(&client, topic, &message)) < 0) {
            printf("mqtt_example: Unable to publish (%d)\n", rc);
        }
        else {
            printf("mqtt_example: Message (%s) has been published to topic %s"
            "with QOS %d\n",
            (char *)message.payload, topic, (int)message.qos);
        }
        thread_sleep();
    }
    return 0;
}

static void _on_msg_received(MessageData *data)
{
    printf("\npaho_mqtt_water_sensor: message received on topic"
           " %.*s: %.*s\n",
           (int)data->topicName->lenstring.len,
           data->topicName->lenstring.data, (int)data->message->payloadlen,
           (char *)data->message->payload);

    mex = (char *)data->message->payload;

    if((strcmp (mex, "heloy"))==0){
        time_s0_son = xtimer_now();
        value_message_on_received="answr";
        thread_wakeup(publish_thread_node); //publish("answr");
        time_s1_son = xtimer_now();
    }

    else if((strcmp (mex, "answr"))==0){
        answer=1;
        time_s1_source = xtimer_now();
        value_message_on_received="start";
        thread_wakeup(publish_thread_node);
        thread_wakeup(water_sensor_thread);
    }

    else if((strcmp (mex, "start"))==0){
        work=1;
        thread_wakeup(water_sensor_thread);
    }

    else{
        if(work==1){
            //thread_wakeup(thread_buzzer);
            //thread_wakeup(thread_led);
            water_flow_rate_other = atof(mex);
            time_s2_son = xtimer_now();
            if(water_flow_rate-water_flow_rate_other > 3 || water_flow_rate_other-water_flow_rate > 3){
                if(water_flow_rate-water_flow_rate_other > 0)
                {    water_flow_diff=water_flow_rate-water_flow_rate_other; }
                else
                {   water_flow_diff=water_flow_rate_other-water_flow_rate;  }

                printf("LEAKEGE DETECTED \t -> \t My flow:%f \t Other: %f \t difference: %f\n",water_flow_rate,water_flow_rate_other,water_flow_diff);                             
                
                total_quantity=total_quantity+water_flow_diff/60*8;
                //sprintf(message, "{\"id\": \"%d\", \"flow_son\": \"%f\", \"flow_diff\": \"%f\", \"quantity leak\": \"%f\"}", board, water_flow_rate, water_flow_diff, total_quantity);             
                sprintf(message, "{\"time_s0_son\": \"%d\", \"time_s1_son\": \"%d\", \"sample_time_now\": \"%d\", \"sample_time_end\": \"%d\", \"time_s2_son\": \"%d\"}", time_s0_son, time_s1_son, sample_time_now, sample_time_end, time_s2_son);             
                message_on_aws=message;
                thread_wakeup(publish_thread_aws);
            }
            else{
                if(water_flow_rate-water_flow_rate_other > 0)
                {    water_flow_diff=water_flow_rate-water_flow_rate_other; }
                else
                {   water_flow_diff=water_flow_rate_other-water_flow_rate;  }

                printf("NO LEAKEGE\n");

                total_quantity=total_quantity+water_flow_diff/60*8;
                //sprintf(message, "{\"id\": \"%d\", \"flow_son\": \"%f\", \"flow_diff\": \"%f\", \"quantity leak\": \"%f\"}", board, water_flow_rate, water_flow_diff, total_quantity);             
                sprintf(message, "{\"time_s0_son\": \"%d\", \"time_s1_son\": \"%d\", \"sample_time_now\": \"%d\", \"sample_time_end\": \"%d\", \"time_s2_son\": \"%d\"}", time_s0_son, time_s1_son, sample_time_now, sample_time_end, time_s2_son);             
                message_on_aws=message;
                thread_wakeup(publish_thread_aws);
            }
        answer=0;    
        work=0;    
        }
    }
    memset(mex,0,strlen(mex));
    //memset(value_message_on_received,0,strlen(value_message_on_received));
}

void sub_to_topic(void)
{
    enum QoS qos = QOS0;
    printf("usage: %s <topic name> [QoS level]\n",DEFAULT_TOPIC_SUB);

    printf("mqtt_example: Subscribing to %s\n", DEFAULT_TOPIC_SUB);
    int ret = MQTTSubscribe(&client,DEFAULT_TOPIC_SUB, qos, _on_msg_received);
    if (ret < 0) {
        printf("mqtt_example: Unable to subscribe to %s (%d)\n",
               DEFAULT_TOPIC_SUB, ret);
        //_cmd_discon(0, NULL);
    }
    else {
        printf("\nmqtt_example: Now subscribed to %s, QOS %d\n",
               DEFAULT_TOPIC_SUB, (int) qos);
     
    }

    return;
}

int water_sensor_test(void){

    printf(" \n- - - - - - - - - - - - - - - - - - - - - - - - - - - - \n");
    printf("water sensor test start\n");
    
    int middle_turn=-1;
    int sample=0;
    float number_turn=0.0;
    
    sample = adc_sample(WATER_FLOW,ADC_RES);
    sample_time_now=xtimer_now();

    while(1){
        sample = adc_sample(WATER_FLOW,ADC_RES);
        
        if (middle_turn==0 && sample==4095){
            number_turn++;
        }
        middle_turn=sample;
        
        sample_time_end=xtimer_now();
        sample_time_diff=xtimer_diff(sample_time_end, sample_time_now); //microsecondi
        
        if(sample_time_diff > TESTING && number_turn==0.0){
            if(board!=0){
                break; //se no flow nella seconda va controllato il leakage
            }
            printf("No flow detected\n");
            return 0;
        }
        if(sample_time_diff > TESTING && number_turn!=0.0){
            printf("water flow detected\n");
            
            return 1;
        }
    }

    return 0;
}

void* water_sensor_sampling(void* arg){
    while(1){ 
        printf("water sensor  sampling thread start\n");
        
        int middle_turn=-1;
        int sample=0;

        float number_turn=0.0;
        float remain=0.0;
        float frequency=0.0;
        water_flow_rate=0.0;
        
        sample = adc_sample(WATER_FLOW,ADC_RES);

        if (sample==0){
            //middle_turn=0;
            remain=1;
        }
        else{ 
            //middle_turn=0;  
        }
        
        sample_time_now=xtimer_now();

        while(1){
            sample = adc_sample(WATER_FLOW,ADC_RES);
            
            if (middle_turn==0 && sample==4095){
                number_turn++;
            }
            middle_turn=sample;
            
            sample_time_end=xtimer_now();
            sample_time_diff=xtimer_diff(sample_time_end, sample_time_now); //microsecondi
            
            if(sample_time_diff > SAMPLING){
                break;
            }
        }

        if(remain!=0){
            number_turn=number_turn+remain;
        }
        
        printf("time: %d microseconds\t turns: %f\n",sample_time_diff,number_turn);
            
        //Q(L/s) = f/impulsi; -> Q(L/min) = f*60/impulsi  
        //usiamo per ora 541
        frequency=number_turn/(float)sample_time_diff*SECONDS;
        water_flow_rate=(float)frequency*60/541; 
        printf("frequency: %f Hz\t water_flow_rate: %f L/min\n",frequency,water_flow_rate);
        printf("water sensor thread end\n");
        if(board==0){
            time_s2_source = xtimer_now();
            sprintf(message, "%f", water_flow_rate);
            publish(message);
            
            total_quantity=total_quantity+water_flow_rate/60*8;
            //sprintf(message, "{\"id\": \"%d\", \"flow source\": \"%f\", \"quantity\": \"%f\"}", board, water_flow_rate, total_quantity);             
            sprintf(message, "{\"time_s0_source\": \"%d\", \"time_s1_source\": \"%d\", \"time_s2_source\": \"%d\"}", time_s0_source, time_s1_source, time_s2_source); 
            message_on_aws=message;
            thread_wakeup(publish_thread_aws);
        }

        thread_sleep();
    }

    return NULL;
}



int main(void)
{
    if(board==0){
        DEFAULT_TOPIC_SUB = "sub"; //subscribe
        DEFAULT_TOPIC_PUBLISH = "publish"; //publish
    }
    else{
        DEFAULT_TOPIC_SUB = "publish"; //subscribe
        DEFAULT_TOPIC_PUBLISH = "sub"; //publish
    }

    printf("You are running RIOT on a(n) %s board.\n", RIOT_BOARD);

    NetworkInit(&network);
 
    xtimer_sleep(3);

    MQTTClientInit(&client, &network, COMMAND_TIMEOUT_MS, buf, BUF_SIZE,
                   readbuf,
                   BUF_SIZE);

    printf("Running water-sensor example.\n");
  
    xtimer_sleep(3);

    MQTTStartTask(&client);
 
    while(ret<0){
        connect();
        xtimer_sleep(1);
    }

    // initialize the FLAME_PIN (ADC) line
    if (adc_init(WATER_FLOW) < 0) {
        printf("Initialization of ADC_LINE(%u) failed\n", WATER_FLOW);
        return 1;
    } else {
        printf("Successfully initialized ADC_LINE(%u)\n", WATER_FLOW);
    }
    publish_thread_node=thread_create(publish_stack_node, sizeof(publish_stack_node),
                  THREAD_PRIORITY_MAIN - 1, THREAD_CREATE_SLEEPING,
                  publish_on_node, NULL, "publish_on_node");  
	
	water_sensor_thread=thread_create(water_sensor_stack, sizeof(water_sensor_stack),
                  THREAD_PRIORITY_MAIN + 1, THREAD_CREATE_SLEEPING,
                  water_sensor_sampling, NULL, "water_sensor");

    publish_thread_aws=thread_create(publish_stack, sizeof(publish_stack),
                  THREAD_PRIORITY_MAIN - 1, THREAD_CREATE_SLEEPING,
                  publish_on_aws, NULL, "publish_on_received");              

    sub_to_topic();
    periodic_time = xtimer_now(); 
    
    while(1){
        /*
        if(board==0){

            while(1){  
                if(water_sensor_test()==1){
                    time_s0_source = xtimer_now();
                    publish("heloy");
                    xtimer_periodic_wakeup(&periodic_time, ANSWER_AGAIN_PERIODIC);
                    while(1){
                        if(answer==0){
                            printf("To do again, no answer from son\n");
                            time_s0_source = xtimer_now();
                            publish("heloy");
                            xtimer_periodic_wakeup(&periodic_time, ANSWER_AGAIN_PERIODIC);
                        }
                        else{
                            break;
                        }
                    }
                    break;
                }   
                else{
                    printf("To do again, no water\n");
                    xtimer_periodic_wakeup(&periodic_time, NO_WATER_AGAIN_PERIODIC);
                } 
            }

            time_s1_source = xtimer_now();
            value_message_on_received="start";
            thread_wakeup(publish_thread_node);
            thread_wakeup(water_sensor_thread);
            //publish("start");
            
            printf("I am doing the sampling\n");
            xtimer_periodic_wakeup(&periodic_time, DAILY_PERIODIC);
            if(ret<0){
                connect();
                xtimer_sleep(1);
            }
        } 
        */
        if(board==0){

            while(1){  
                if(water_sensor_test()==1){
                    time_s0_source = xtimer_now();
                    publish("heloy");
                }
                xtimer_periodic_wakeup(&periodic_time, DAILY_PERIODIC);
                if(ret<0){
                    connect();
                    xtimer_sleep(1);
                }
            } 
        }

        if(board!=0){
            while(1){
                xtimer_periodic_wakeup(&periodic_time, DAILY_PERIODIC);
                if(ret<0){
                    connect();
                    xtimer_sleep(1);
                }
            }
        }  

    }

    printf("main thread end\n");

	return 0;
    
}    

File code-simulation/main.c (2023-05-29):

#include <stdio.h>
#include <string.h>
#include <stdlib.h>

#include "thread.h"
#include "fmt.h"

#include "xtimer.h"

#include "shell.h"

#include "drivers_sx127x.h"
#include "semtech-loramac.h"
#include "behaviors.h"
#include "config.h"
#include "app_debug.h"
    
static node_t node;

int node_config(int argc, char **argv)
{
    if (argc <= 1) {
        puts("usage: config <node-code>");
        return -1;
    }

    node.node_self = NULL;
    node.node_alt_self = NULL;
    node.node_source_p2p = NULL;
    node.node_father = NULL;
    node.node_children = NULL;
    node.node_type = 2;
    node.children_count = 0;
    node.self_children_position = 0;

    int valid_node = 0;

    /* Extracting configuration information */
    char* buffer = config();
    int buf_len = strlen(buffer);
    char buf[buf_len + 1];
    strncpy(buf, buffer, buf_len + 1);

    char** pairs = NULL;
    int pair_count = 0;
 
    /* First pair */
    char* pair = strtok(buf, " ");
    int length;

    /* Extracting pairs */
    while (pair != NULL) {
        pair_count++;
        pairs = realloc(pairs, pair_count*sizeof(char*));
        length = strlen(pair);
        pairs[pair_count - 1] = malloc(length + 1);
        strncpy(pairs[pair_count - 1], pair, length + 1);
        pair = strtok(NULL, " ");
    }

    for (int i=0; i < pair_count; i++) {

        /* Separate elements for current pair */
        char *elem = strtok(pairs[i], "-");
        length = strlen(elem);
        char *elem1 = malloc(length + 1);
        strncpy(elem1, elem, length + 1);

        elem = strtok(NULL, "-");
        length = strlen(elem);
        char *elem2 = malloc(length + 1);
        strncpy(elem2, elem, length + 1);
        
        if (i == 0) {
            /* Store source_p2p */
            length = strlen(elem2);
            node.node_source_p2p = (char*)malloc(length + 1);
            strncpy(node.node_source_p2p, elem2, length + 1);
            
            //printf("#%d Source TTN: st-lrwan1-%s\t Source P2P: st-lrwan1-%s\n", i, elem1, elem2);
            if (strcmp(elem1, argv[1]) == 0) {
                valid_node = 1;
                /* Source TTN is simply considered as a node without father and without children */
                node.node_type = 0;
                length = strlen(elem2);
                node.node_alt_self = malloc(length + 1);
                strncpy(node.node_alt_self, elem2, length + 1);
            }
            if (strcmp(elem2, argv[1]) == 0) {
                length = strlen(elem1);
                node.node_alt_self = malloc(length + 1);
                strncpy(node.node_alt_self, elem1, length + 1);
            }
        }
        else {
            //printf("#%d Father: st-lrwan1-%s\t Child: st-lrwan1-%s\n", i, elem1, elem2);

            if (strcmp(elem2, argv[1]) == 0) {
                valid_node = 1;
                length = strlen(elem1);
                node.node_father = malloc(length + 1);
                strncpy(node.node_father, elem1, length + 1);
            }

            if (strcmp(elem1, argv[1]) == 0) {
                valid_node = 1;
                node.children_count++;
                node.node_children = realloc(node.node_children, node.children_count*sizeof(char*));
                length = strlen(elem2);
                node.node_children[node.children_count - 1] = malloc(length + 1);
                strncpy(node.node_children[node.children_count - 1], elem2, length + 1);
                node.self_children_position = node.children_count;
            }
        }
        
        /* Free allocated memory */
        free(elem1);
        free(elem2);
        elem1 = NULL;
        elem2 = NULL;

    }
    
    /* Check if node is valid */
    if (!valid_node) {
        printf("config: node not valid for current topology.\n");
        return -1;
    }

    /* Assign node_self*/
    int node_length = strlen(argv[1]);
    node.node_self = (char*)malloc(sizeof(char)*(node_length+1));
    strncpy(node.node_self, argv[1], node_length + 1);

    /* Display node information */
    printf("Node: st-lrwan1-%s\n", argv[1]);

    if (node.node_type != 0) {

        /* Display father information */
        printf("Father of %s: ", argv[1]);
        if (node.node_father == NULL) {
            node.node_type = 1;
            printf("undefined, CHIEF is the root of the tree.\n");
        }
        else {
            printf("st-lrwan1-%s\n", node.node_father);
        }

        /* Display children information */
        printf("Children of %s: ", argv[1]);
        if (node.node_children == NULL) {
            node.node_type = 3;
            printf("undefined, BRANCH is a leaf of the tree.\n");
        }
        else {
            for (int i = 0; i < node.children_count; i++) printf("st-lrwan1-%s ", node.node_children[i]);
            printf("\n");
        }
    }

    printf("Node type: ");
    if (node.node_type == 0) {
        printf("Source TTN\n");
        printf("Known CHIEF (P2P source): st-lrwan1-%s\n", node.node_alt_self);
    }
    else if (node.node_type == 1) {
        printf("CHIEF\n");
        printf("Known TTN source: st-lrwan1-%s\n", node.node_alt_self);
    }
    else if (node.node_type == 2) printf("FORK\n");
    else printf("BRANCH\n");

    return 0;
}

int check_configuration(void) {

    if (APP_DEBUG) {
        if (node.node_self == NULL) {
            printf("node_self is NULL\n");
        } else {
            printf("node_self: %s\n", node.node_self);
        }
        if (node.node_father == NULL) {
            printf("node_father is NULL\n");
        } else {
            printf("node_father: %s\n", node.node_father);
        }
        if (node.node_children == NULL) {
            printf("node_children is NULL\n");
        } else {
            printf("node_children: %s\n", *(node.node_children));
        }
    }

    /* node_self should always be set, also one between node_father and node_children */
    if (!node.node_self) {
        puts("Configuration error: node_self is NULL");
        return 1;
    } 
    if (!node.node_children && !node.node_father && node.node_type != 0) {
        puts("Configuration error: at least one between node_children and node_father ");
        return 1;
    }
    return 0;
}
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

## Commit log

2023-05-13 Inserting shell commands
2023-05-14 Inserting driver 127x
2023-05-14 Inserting lorawan
2023-05-15 Commenting drivers
2023-05-15 Inserting loramac shell command
2023-05-17 Fixing compiling problems in main.c
    [main.c]
2023-05-19 Inserting new config command
2023-05-20 Adding samples generator
2023-05-21 Inserting a node struct
2023-05-21 Update water flow generator
2023-05-21 Inserting sending lora message
2023-05-21 Update sample generator
2023-05-21 Update sample_generator
2023-05-24 Debugging threads
2023-05-24 Inserting debugging
2023-05-27 Inserting leakage messaging
2023-05-27 Remove prints
2023-05-27 Fixing prints
2023-05-29 Inserting calllback to wait sx17x send
2023-05-29 Inserting Simulation status images
2023-05-29 Inserting simulation status images into the markdown
2023-06-10 Changing starting sample
2023-06-10 feat: inserting an assert for the lora p2p message payload
2023-06-10 feat: generate float water flows
2023-06-10 fix double to float
    [main.c]
2023-06-12 feat adding sending thread
2023-06-12 fix prints
2023-06-13 Insert iot-lab energy consumption images
2023-06-15 Inserting Design leakage images
2023-06-18 fix: removing UART logic
2023-06-18 feat: adding sample_generator in Design
    [sample_generator_data.csv]
